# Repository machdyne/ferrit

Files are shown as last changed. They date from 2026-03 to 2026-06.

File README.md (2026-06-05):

# FERRIT Digital Archival Platform

FERRIT is a century-scale digital archival platform based on Ferroelectric RAM.

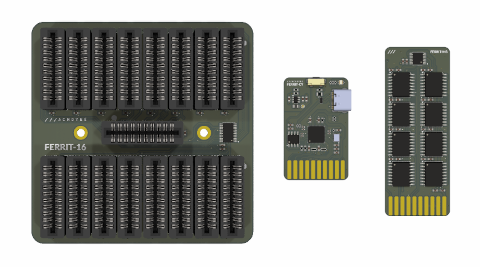
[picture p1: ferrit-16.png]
Ferrit


This repo contains PCB layouts, schematics, firmware and documentation.

Find more information on the [FERRIT project page](https://machdyne.com/ferrit/).

## Hardware

FERRIT is a modular upgradable system with 3 component types:

- A controller
- A backplane
- Removable ferroelectric memory cards

The controller communicates with the memory cards over a SPI/QSPI bus and exposes the memory to an interface, such as a USB mass storage device.

### Specifications

- Max capacity: 256MB+
- Max addressable memory devices per memory card: 16
- Max addressable memory devices per system: 256
- Interface: Depends on controller
- Speed: Depend on controller

*Note: The max capacity assumes double-sided memory cards with 1MB ICs. Higher capacities may be possible in the future.*

### Components

| Board | Type | Notes |
| ----- | ---- | ----- |
| FERRIT-CY | Controller | RP2040 / USB-FS |
| FERRIT-M8 | Memory card | 8 x SOP-16 |
| FERRIT-1 | Backplane + Controller | RP2040 / USB-FS / 1 memory card slot |
| FERRIT-8 | Backplane | 8 memory card slots (1U rack-mount) |
| FERRIT-16 | Backplane | 16 memory card slots |

## Firmware

The firmware can be updated by holding down the BOOT button while plugging in the USB cable, and then dragging and dropping a new UF2 file to the device.

You can build the firmware from source, if you have [pico-sdk](https://github.com/raspberrypi/pico-sdk) installed:

```
$ cd firmware/ferrit
$ mkdir build
$ cd build
$ cmake .. -DPICO_DEFAULT_BOOT_STAGE2_FILE=$PICO_SDK_PATH/src/rp2040/boot_stage2/boot2_generic_03h.S
$ make
```

## Pinouts

### Connector

The FERRIT controller and memory cards use the same form-factor and share certain signals:

| Pin | Controller | Memory Card |
| --- | --- | --- |
| 1 | QSPI\_SCLK | QSPI\_SCLK |
| 3 | GND | GND |
| 5 | QSPI\_SD0 | QSPI\_SD0 |
| 7 | GND | GND |
| 9 | QSPI\_SD1 | QSPI\_SD1 |
| 11 | GND | GND |
| 13 | QSPI\_SD2 | QSPI\_SD2 |
| 15 | GND | GND |
| 17 | QSPI\_SD3 | QSPI\_SD3 |
| 19 | GND | GND |
| 2 | QSPI\_SS | QSPI\_SS |
| 4 | SS0 | GND |
| 6 | CS0 | CS0 |
| 8 | CS1 | CS1 |
| 10 | CS2 | CS2 |
| 12 | CS3 | CS3 |
| 14 | SS1 | GND |
| 16 | SS2 | GND |
| 18 | SS3 | GND |
| 20 | PWR3V3 | PWR3V3 |

The slot select (SSx) signals determine which slot is selected, while the chip select (CSx) signals select an IC on that slot.

## License

The contents of this repo are released under the [Lone Dynamics Open License](LICENSE.md).

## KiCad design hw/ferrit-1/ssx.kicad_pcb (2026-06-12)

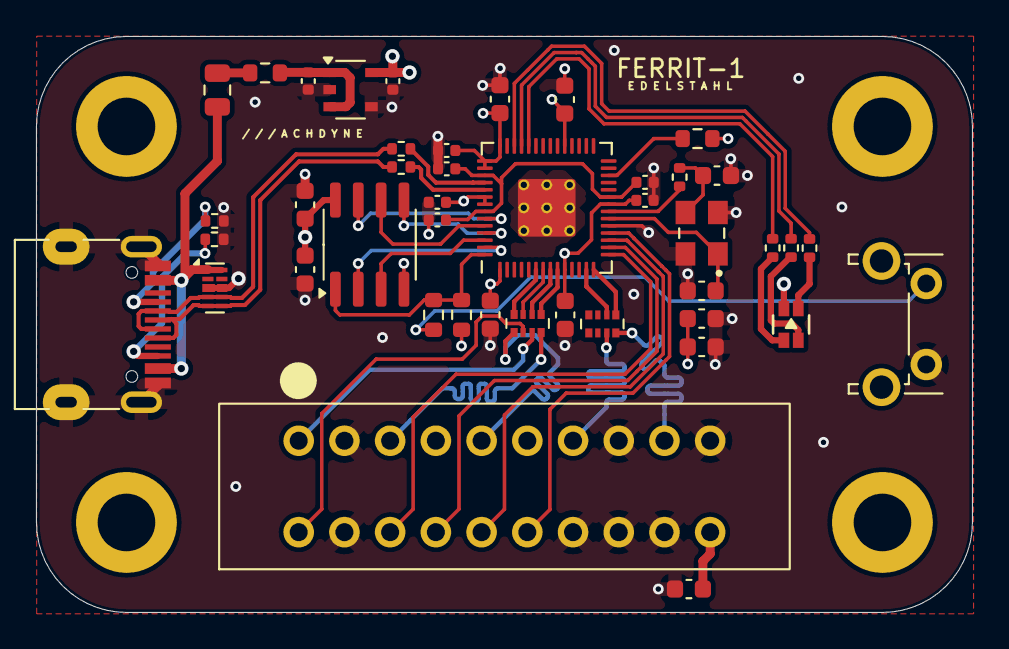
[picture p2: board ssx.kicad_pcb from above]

Board: 4 copper layers, 52.0 x 32.0 mm, 47 parts (0 on the bottom side), 45 nets.

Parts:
C1, C2: 15pF; C_0603_1608Metric
C3, C10, C16, C17: 1uF; C_0402_1005Metric
C4, C6, C8, C9: 100nF; C_0402_1005Metric
C5, C7, C11, C12, C13, C15: 100nF; C_0603_1608Metric
C14: 1uF; C_0603_1608Metric
C19, C20: 22uF; C_0603_1608Metric
D1: LED_RGB_ANODE; LED_RGB_0606_CHANZON
F1: Fuse_Small; Fuse_0805_2012Metric
FB1: Ferrite_Bead_Small; R_0603_1608Metric
H1, H2, H3, H4: MountingHole; MountingHole_3.2mm_M3_DIN965_Pad
J1: USB_C_Receptacle_USB2.0_16P; USB_C_Receptacle_HRO_TYPE-C-31-M-12-BIG-PADS-PASTE
J2: Conn_02x10_Odd_Even; MACHDYNE_EDGE_SOCKET_20P
R1, R7: 10K; R_0603_1608Metric
R2, R3: 27R; R_0402_1005Metric
R4, R11, R12, R13: 1K; R_0402_1005Metric
R5, R6: 5K1; R_0402_1005Metric
R8: 1K; R_0603_1608Metric
RN1, RN2: 33R; R_Array_Convex_4x0402
SW1: BOOT; SW_Tactile_SPST_Angled_PTS645Vx39-2LFS
U1: RP2040; RP2040-QFN-56-OFFICIAL
U2: TPD4E05U06DQAR; Diodes_UDFN-10_1.0x2.5mm_P0.5mm
U3: M95P32-IXMNT/E; SOIC-8_3.9x4.9mm_P1.27mm
U4: NCP115; TSOP-5_1.65x3.05mm_P0.95mm
Y1: ECS-80-12-33-JGN-TR-12MHZ; XTAL_ECS-240-8-33-AGN-TR

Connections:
/BOOT: R8.1, SW1.1
/CS0: J2.6, U1.15 (GPIO12)
/CS1: J2.8, U1.16 (GPIO13)
/CS2: J2.10, U1.17 (GPIO14)
/CS3: J2.12, U1.18 (GPIO15)
/KQSPI_SCLK: J2.1, RN1.7 (R2.2)
/KQSPI_SD0: J2.5, RN1.8 (R1.2)
/KQSPI_SD1: J2.9, RN1.5 (R4.2)
/KQSPI_SD2: J2.13, RN2.7 (R2.2)
/KQSPI_SD3: J2.17, RN2.8 (R1.2)
/KSS: J2.2, RN1.6 (R3.2)
/LEDB: R13.2, U1.40 (GPIO28/ADC2)
/LEDG: R12.2, U1.39 (GPIO27/ADC1)
/LEDR: R11.2, U1.38 (GPIO26/ADC0)
/PWR1V1: C6.1, C8.1, C10.1, U1.23 (DVDD), U1.45 (VREG_VOUT), U1.50 (DVDD)
/PWR3V3: C3.1, C4.1, C5.1, C7.1, C9.1, C11.1, C12.1, C13.1, C14.1, C15.1, C17.1, C19.1, C20.1, D1.1 (A), J2.20, R1.1, R7.1, U1.1 (IOVDD), U1.10 (IOVDD), U1.22 (IOVDD), U1.33 (IOVDD), U1.42 (IOVDD), U1.43 (ADC_AVDD), U1.44 (VREG_VIN), U1.48 (USB_VDD), U1.49 (IOVDD), U3.8 (VCC), U4.5 (OUT)
/PWR5V0: C16.1, FB1.1, U4.1 (IN), U4.3 (EN)
/QSPI_IO0: RN1.1 (R1.1), U1.9 (GPIO7)
/QSPI_IO1: RN1.4 (R4.1), U1.6 (GPIO4)
/QSPI_IO2: RN2.2 (R2.1), U1.13 (GPIO10)
/QSPI_IO3: RN2.1 (R1.1), U1.14 (GPIO11)
/QSPI_SCLK: RN1.2 (R2.1), U1.8 (GPIO6)
/RP_QSPI_IO0: U1.53 (QSPI_SD0), U3.5 (DI(IO0))
/RP_QSPI_IO1: U1.55 (QSPI_SD1), U3.2 (DO(IO1))
/RP_QSPI_IO2: U1.54 (QSPI_SD2), U3.3 (IO2)
/RP_QSPI_IO3: U1.51 (QSPI_SD3), U3.7 (IO3)
/RP_QSPI_SCK: U1.52 (QSPI_SCLK), U3.6 (CLK)
/RP_QSPI_SS: R7.2, R8.2, U1.56 (QSPI_CSN), U3.1 (~CS)
/RUN: R1.2, U1.26 (RUN)
/SS: RN1.3 (R3.1), U1.7 (GPIO5)
/USBCDN: J1.A7 (D-), J1.B7 (D-), R3.1, U2.4, U2.7
/USBCDP: J1.A6 (D+), J1.B6 (D+), R2.1, U2.5, U2.6
/USBC_CC1: J1.A5 (CC1), R5.2
/USBC_CC2: J1.B5 (CC2), R6.2
/USBDN: R3.2, U1.46 (USB_DM)
/USBDP: R2.2, U1.47 (USB_DP)
/VBUS: F1.1, J1.A4 (VBUS), J1.A9 (VBUS), J1.B4 (VBUS), J1.B9 (VBUS), U2.1, U2.10
/XIN: C1.2, U1.20 (XIN), Y1.1 (IN/OUT)
/XOUT: R4.2, U1.21 (XOUT)
GND: C1.1, C2.2, C3.2, C4.2, C5.2, C6.2, C7.2, C8.2, C9.2, C10.2, C11.2, C12.2, C13.2, C14.2, C15.2, C16.2, C17.2, C19.2, C20.2, J1.A1 (GND), J1.A12 (GND), J1.B1 (GND), J1.B12 (GND), J1.S1 (SHIELD), J2.3, J2.4, J2.7, J2.11, J2.14, J2.15, J2.16, J2.18, J2.19, R5.1, R6.1, SW1.2, U1.19 (TESTEN), U1.57 (GND), U2.3 (VSS), U2.8 (VSS), U3.4 (GND), U4.2 (GND), U4.4 (GND2), Y1.2 (GND), Y1.4 (GND)
unnamed: D1.2 (BK), R13.1
unnamed: D1.4 (GK), R12.1
unnamed: D1.3 (RK), R11.1
unnamed: F1.2, FB1.2
unnamed: C2.1, R4.1, Y1.3 (OUT/IN)

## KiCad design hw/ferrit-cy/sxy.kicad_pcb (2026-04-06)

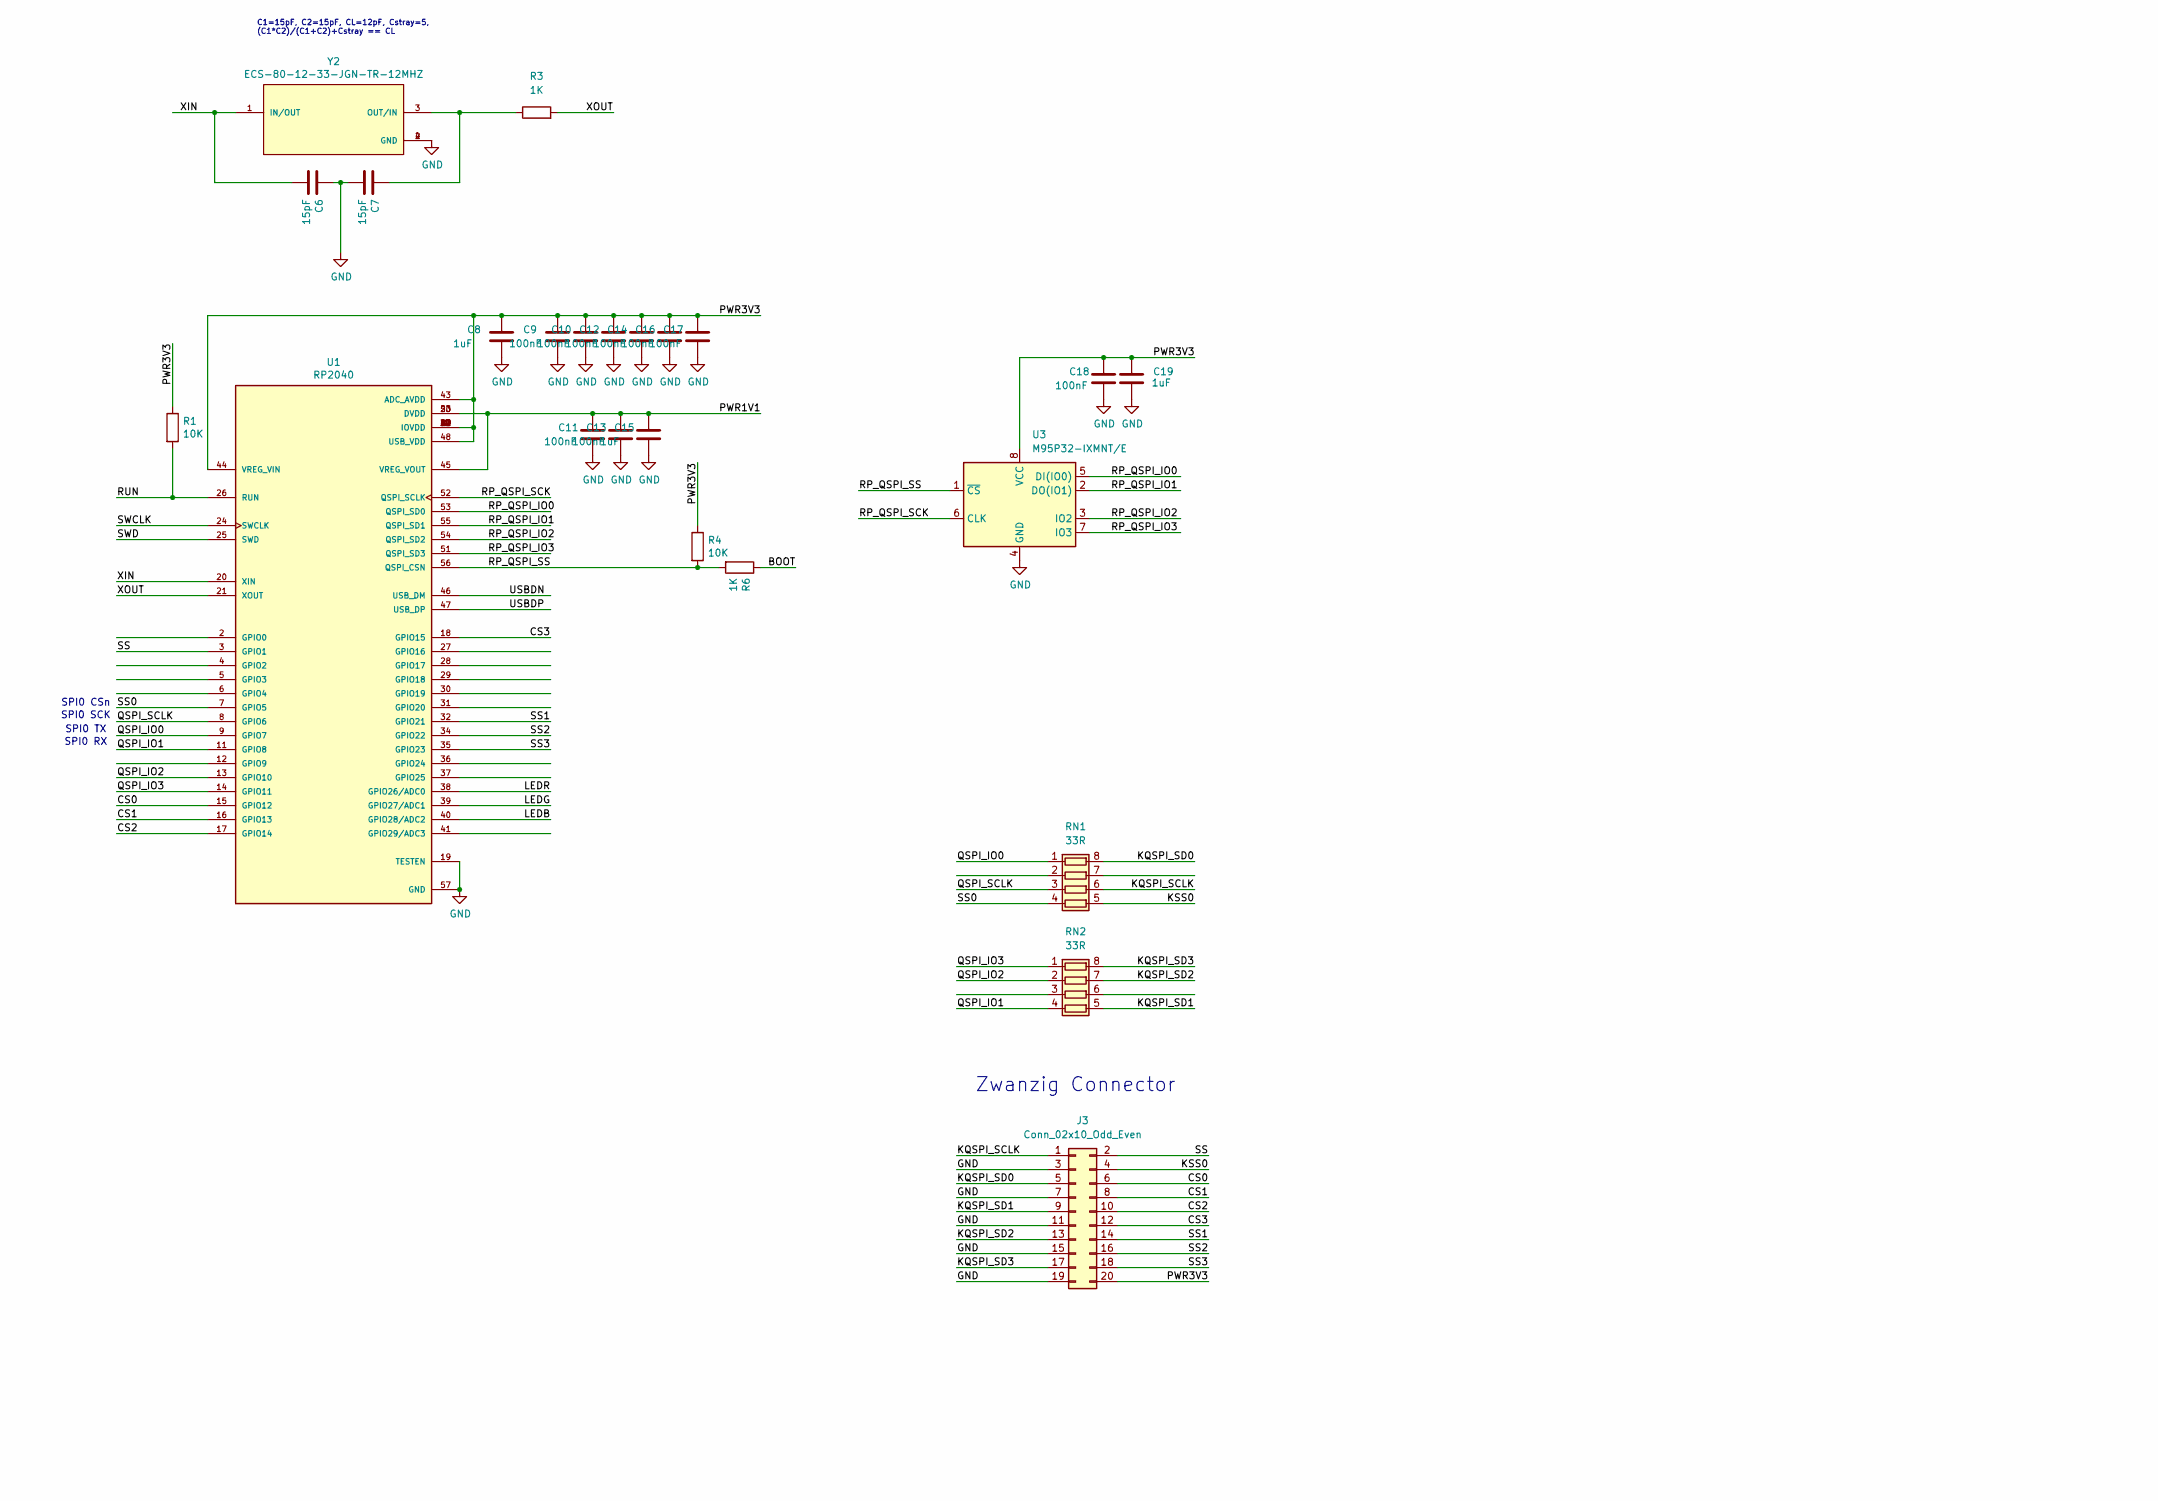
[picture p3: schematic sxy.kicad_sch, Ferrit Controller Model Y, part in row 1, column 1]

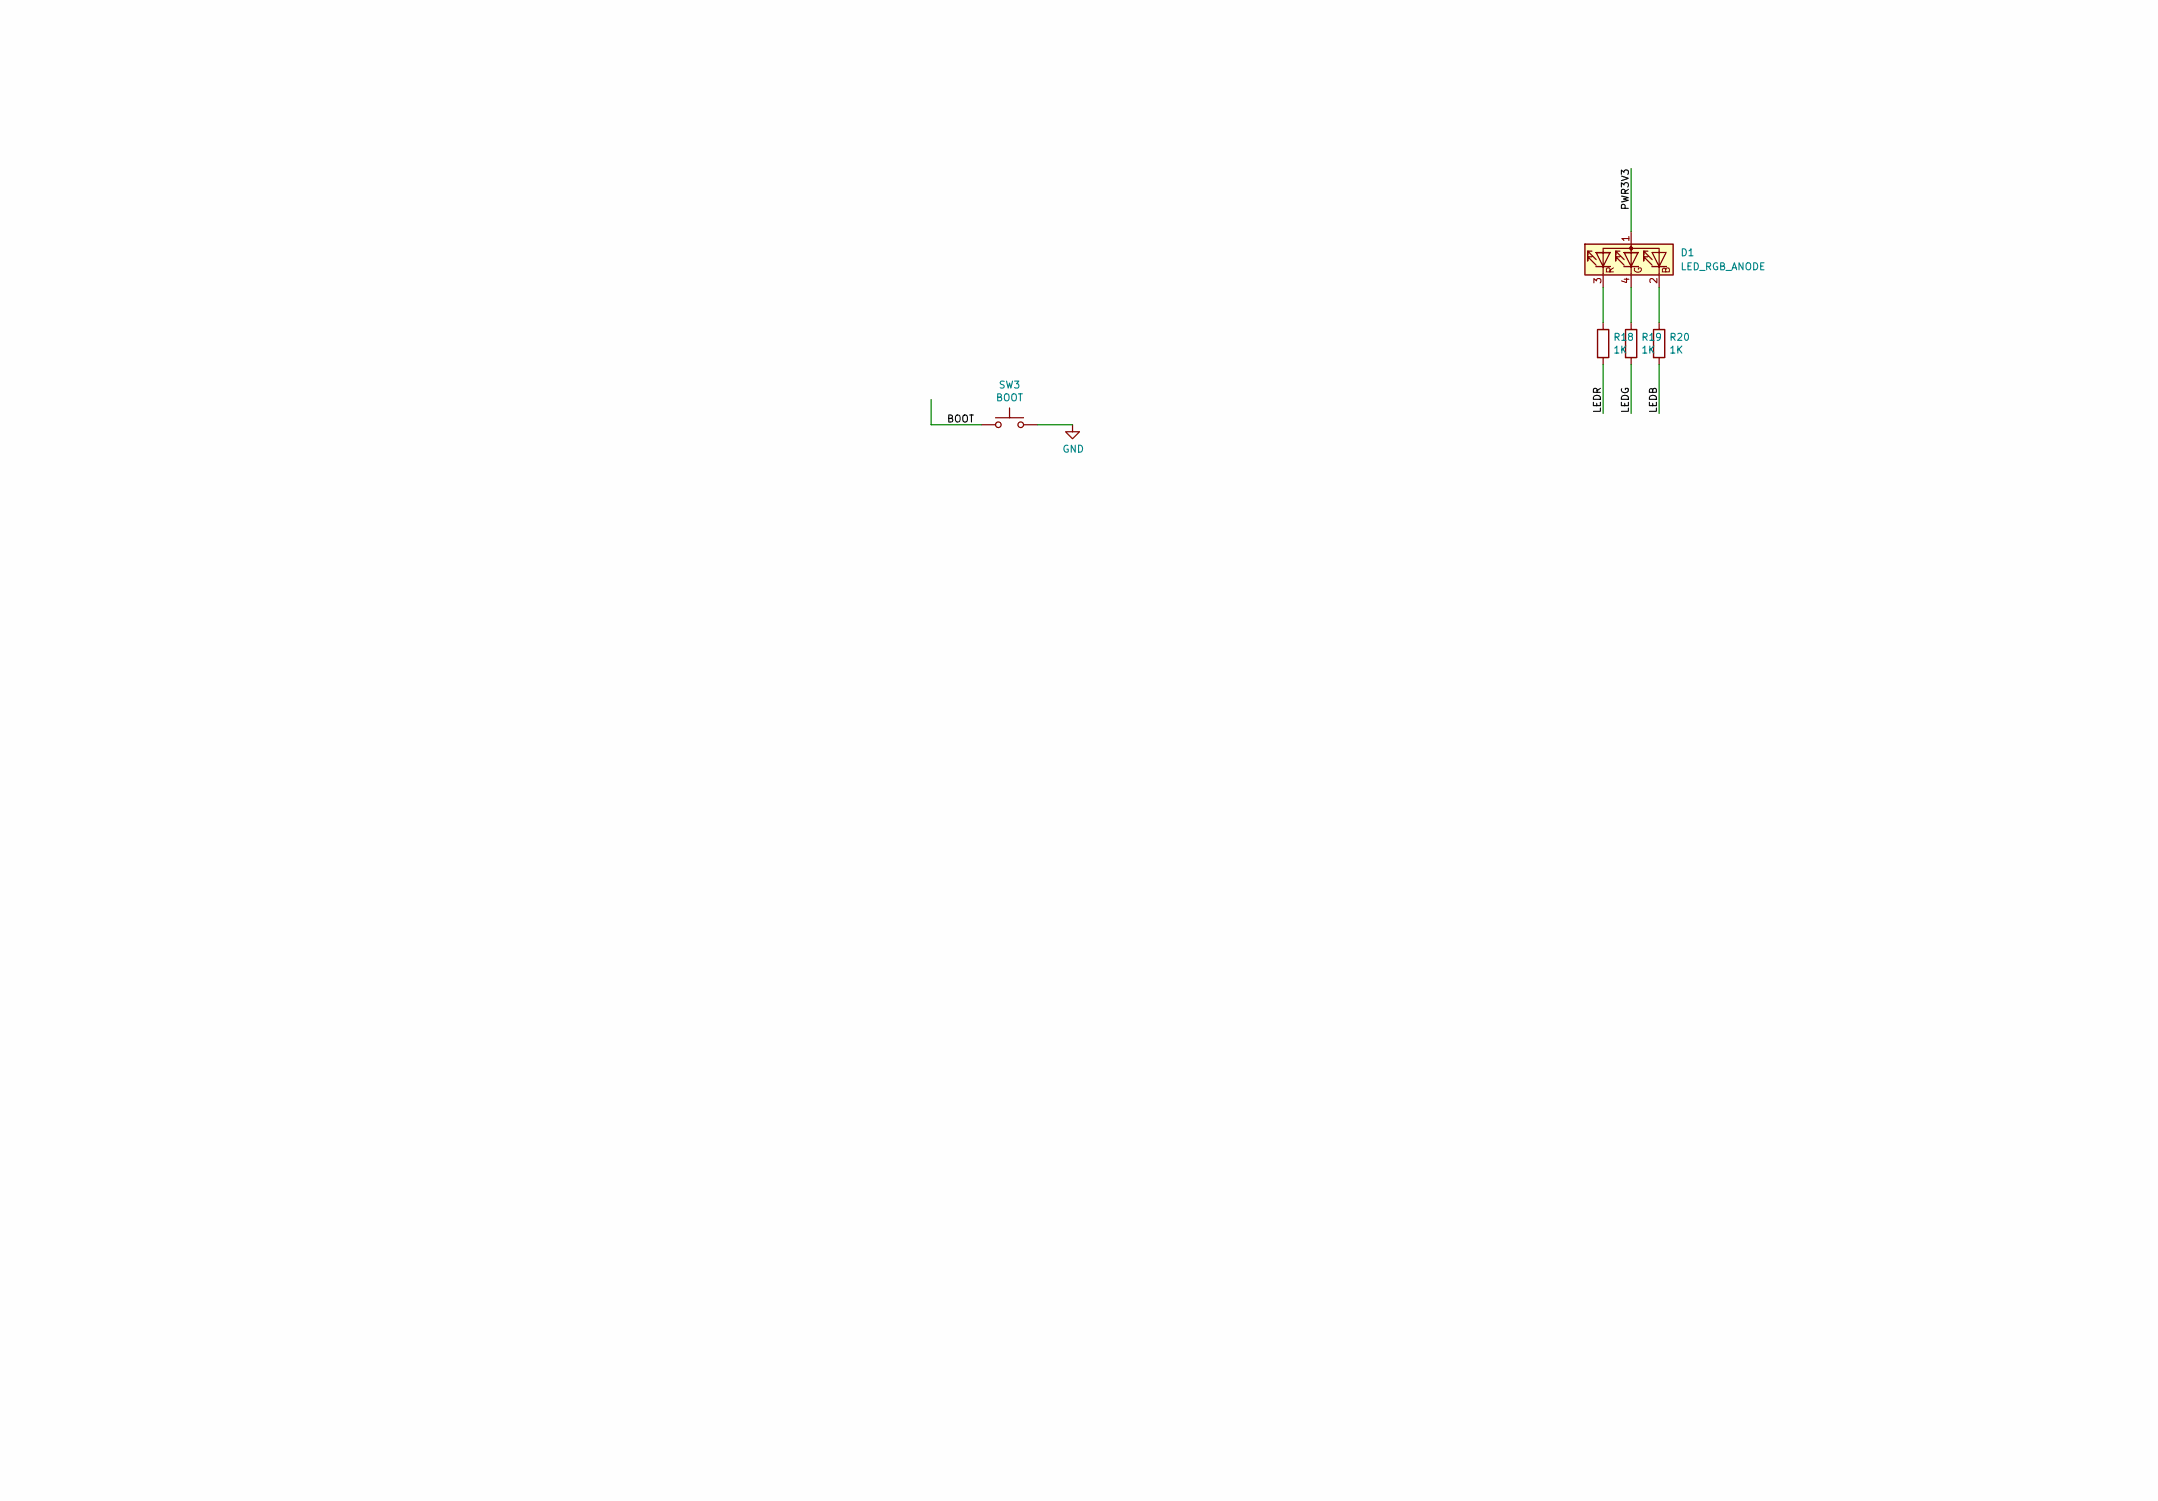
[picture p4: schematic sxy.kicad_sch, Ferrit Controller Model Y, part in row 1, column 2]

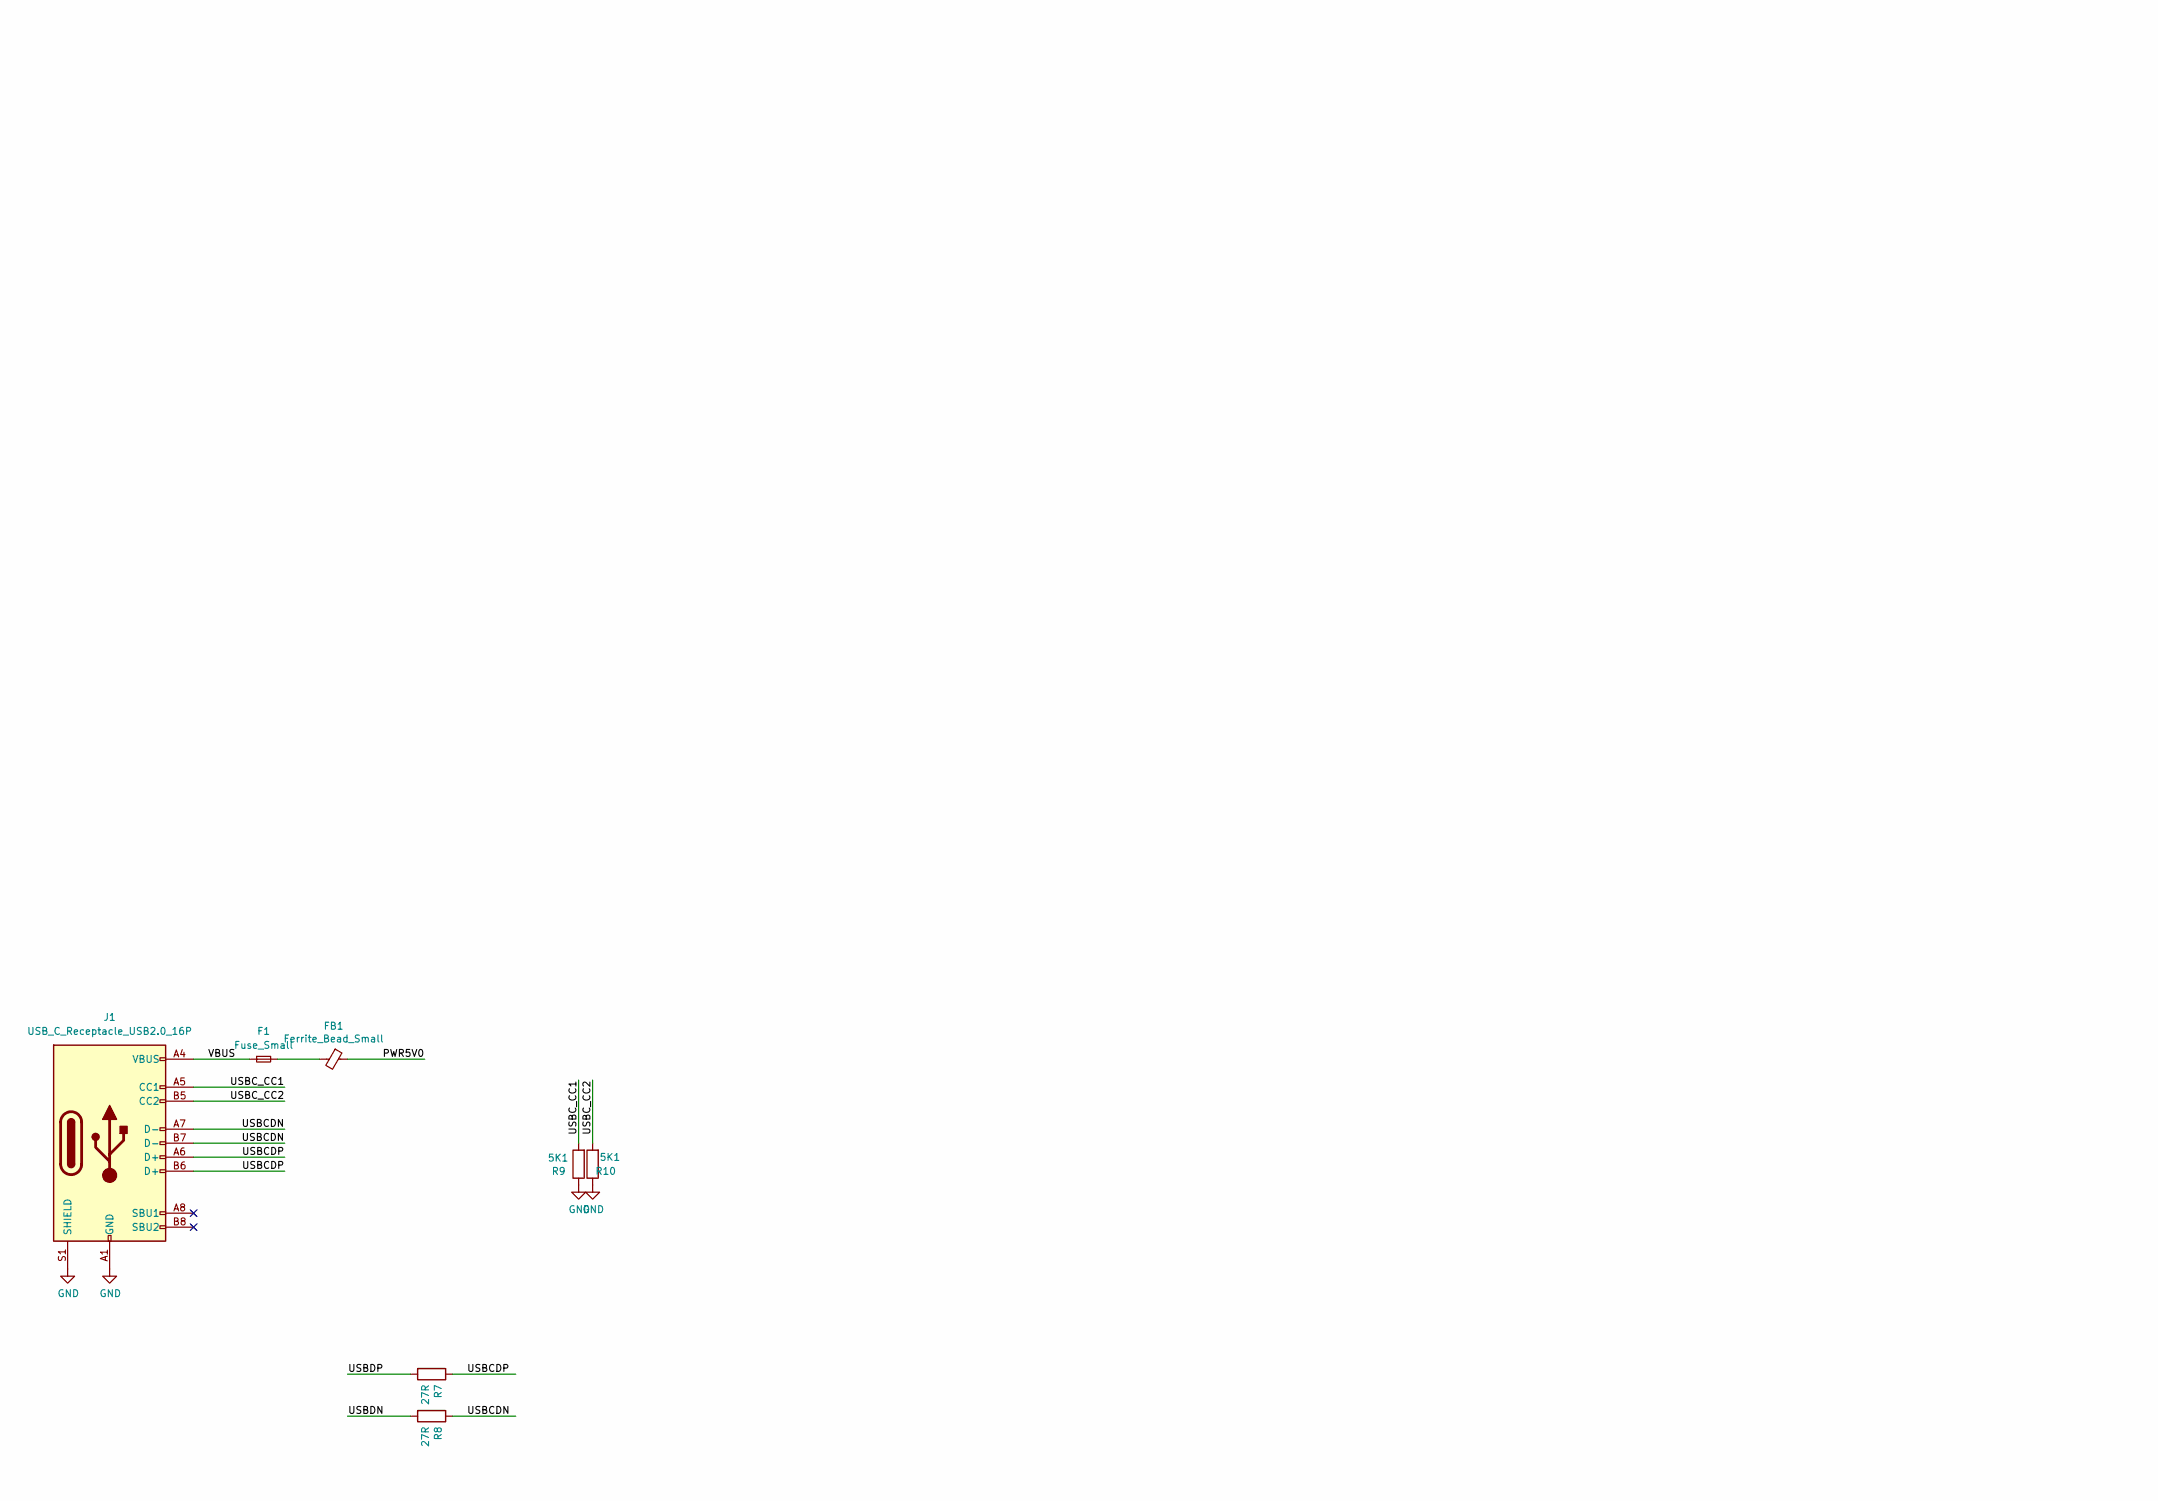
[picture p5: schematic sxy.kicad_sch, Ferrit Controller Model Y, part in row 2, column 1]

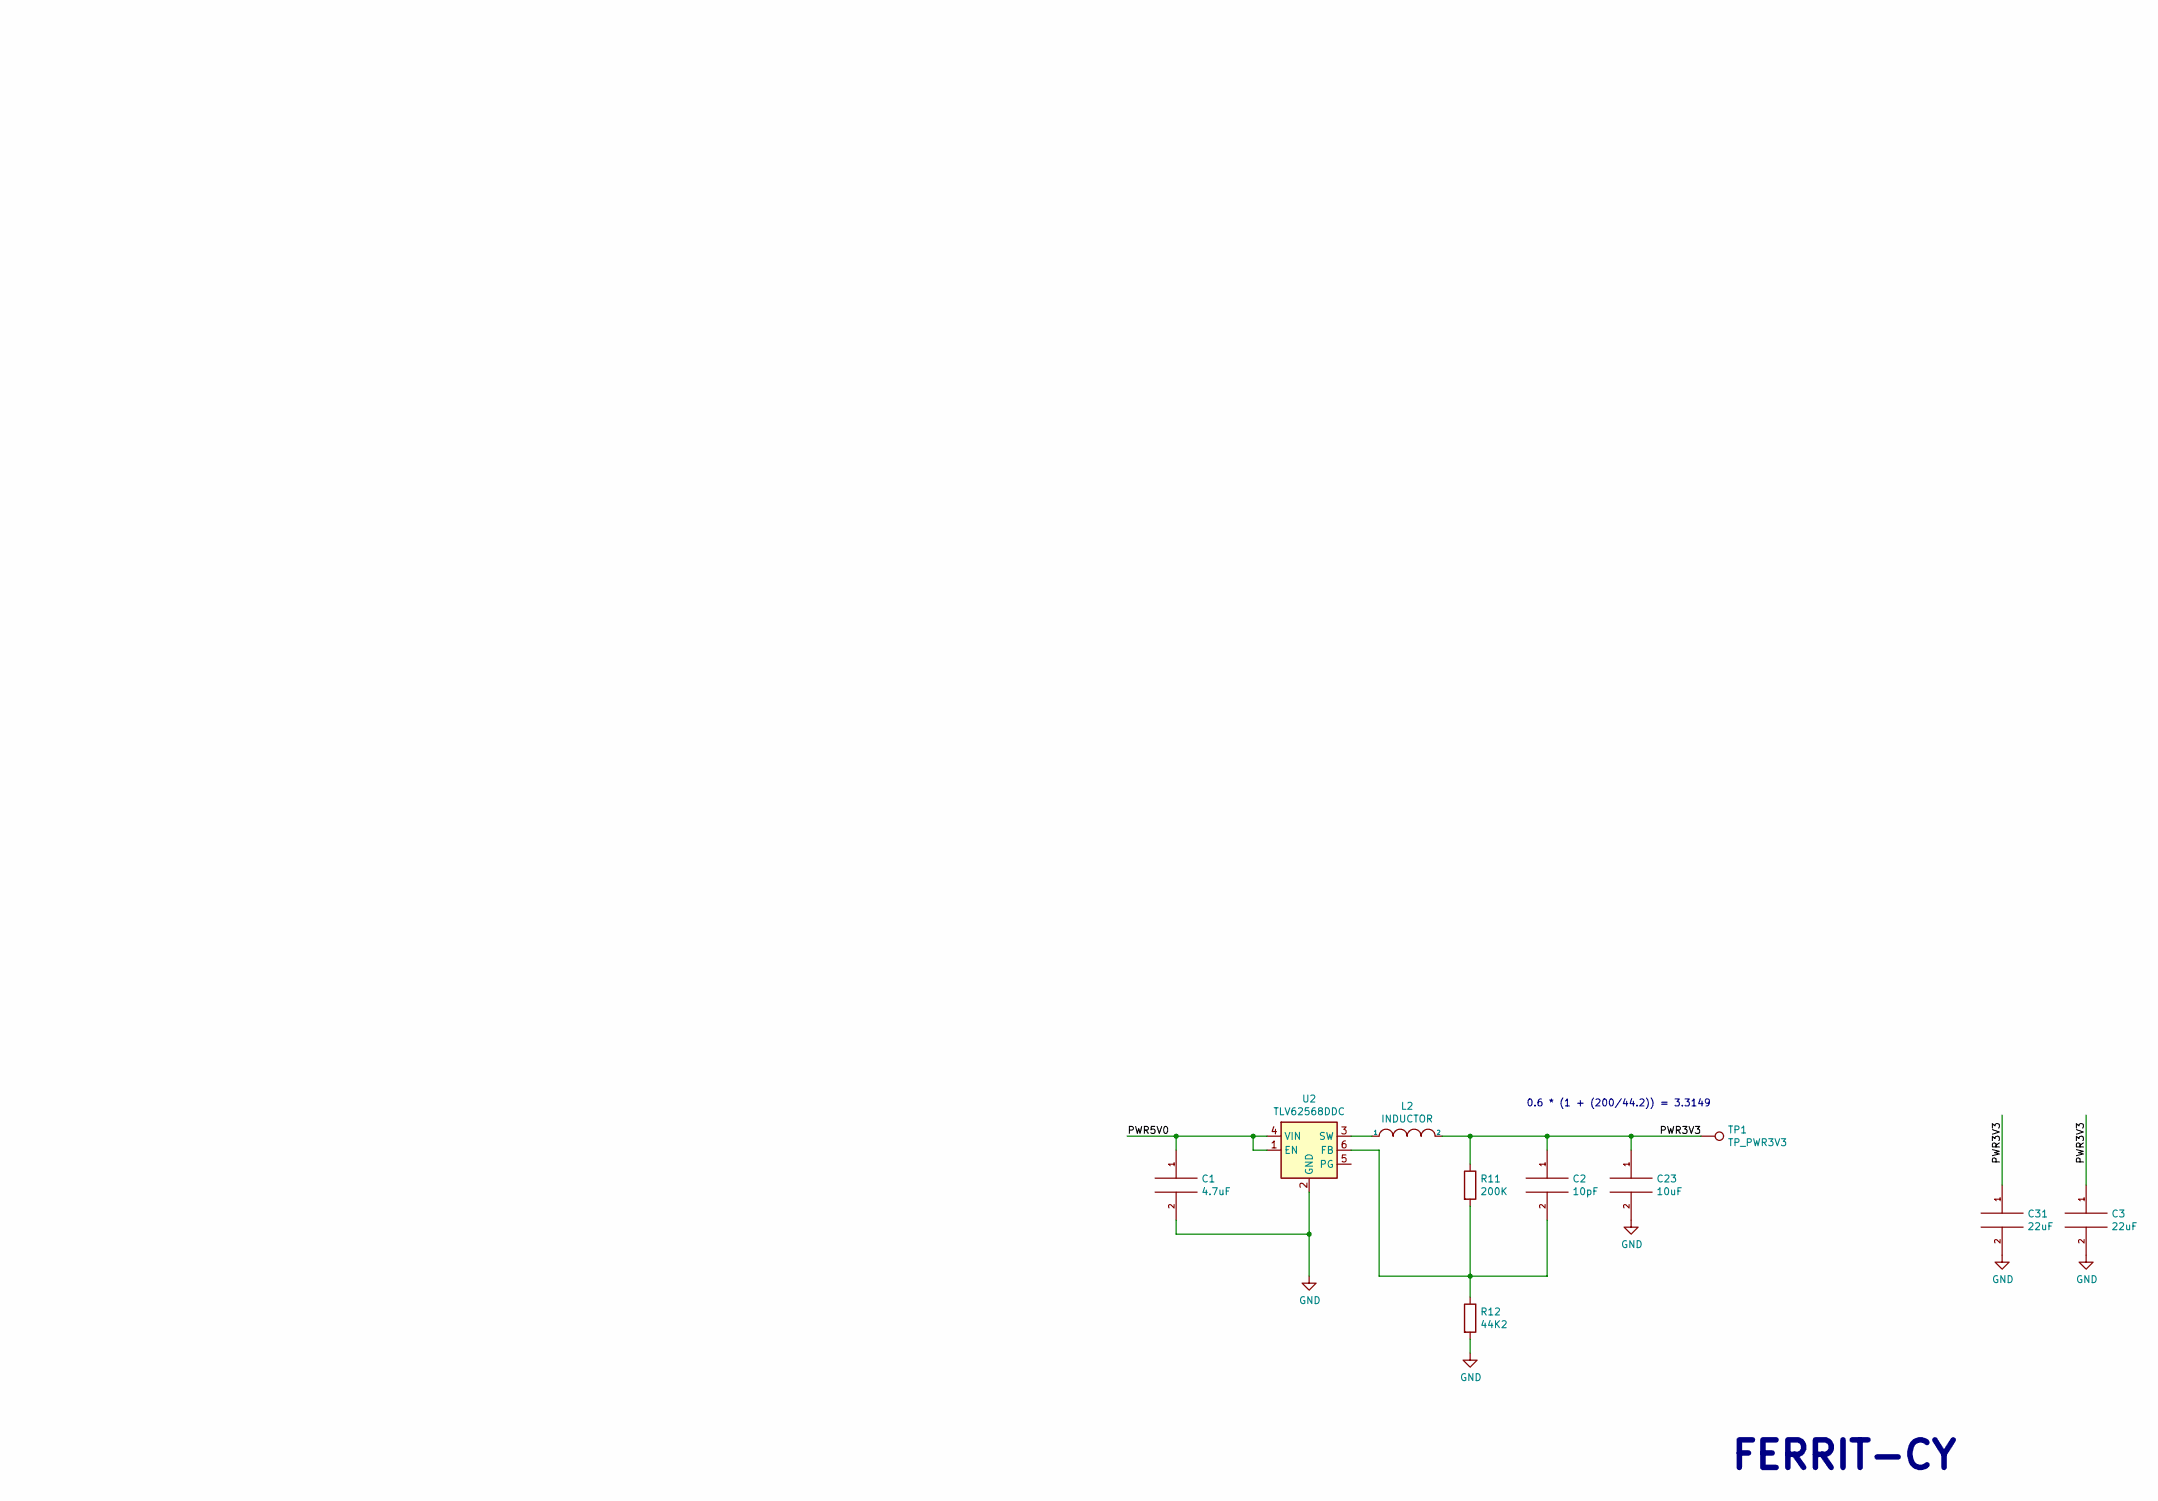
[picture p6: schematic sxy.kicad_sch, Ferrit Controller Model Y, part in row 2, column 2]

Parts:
C1: 4.7uF; C_0603_1608Metric
C2: 10pF; C_0603_1608Metric
C3, C31: 22uF; C_0603_1608Metric
C6, C7: 15pF; C_0603_1608Metric
C8, C15: 1uF; C_0402_1005Metric
C9, C11, C13, C14: 100nF; C_0402_1005Metric
C10, C12, C16, C17, C18: 100nF; C_0603_1608Metric
C19: 1uF; C_0603_1608Metric
C23: 10uF; C_0603_1608Metric
D1: LED_RGB_ANODE; LED_RGB_0606_CHANZON
F1: Fuse_Small; Fuse_0805_2012Metric
FB1: Ferrite_Bead_Small; R_0603_1608Metric
J1: USB_C_Receptacle_USB2.0_16P; USB_C_Receptacle_HRO_TYPE-C-31-M-12-BIG-PADS-PASTE
J3: Conn_02x10_Odd_Even; MACHDYNE_EDGE_20P
L2: INDUCTOR; L_0805_2012Metric
R1, R4: 10K; R_0603_1608Metric
R3, R18, R19, R20: 1K; R_0402_1005Metric
R6: 1K; R_0603_1608Metric
R7, R8: 27R; R_0402_1005Metric
R9, R10: 5K1; R_0402_1005Metric
R11: 200K; R_0603_1608Metric
R12: 44K2; R_0603_1608Metric
RN1, RN2: 33R; R_Array_Convex_4x0402
SW3: BOOT; SW_SMD_2P_3X6MM
TP1: TP_PWR3V3; TestPoint_THTPad_D1.0mm_Drill0.5mm
U1: RP2040; RP2040-QFN-56-OFFICIAL; PARTREV 1.6.1
U2: TLV62568DDC; SOT-23-6
U3: M95P32-IXMNT/E; SOIC-8_3.9x4.9mm_P1.27mm
Y2: ECS-80-12-33-JGN-TR-12MHZ; XTAL_ECS-240-8-33-AGN-TR

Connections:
/BOOT: R6.1, SW3.1
/CS0: J3.6, U1.15 (GPIO12)
/CS1: J3.8, U1.16 (GPIO13)
/CS2: J3.10, U1.17 (GPIO14)
/CS3: J3.12, U1.18 (GPIO15)
/KQSPI_SCLK: J3.1, RN1.6 (R3.2)
/KQSPI_SD0: J3.5, RN1.8 (R1.2)
/KQSPI_SD1: J3.9, RN2.5 (R4.2)
/KQSPI_SD2: J3.13, RN2.7 (R2.2)
/KQSPI_SD3: J3.17, RN2.8 (R1.2)
/KSS0: J3.4, RN1.5 (R4.2)
/LEDB: R20.2, U1.40 (GPIO28/ADC2)
/LEDG: R19.2, U1.39 (GPIO27/ADC1)
/LEDR: R18.2, U1.38 (GPIO26/ADC0)
/PWR1V1: C11.1, C13.1, C15.1, U1.23 (DVDD), U1.45 (VREG_VOUT), U1.50 (DVDD)
/PWR3V3: C2.1, C3.1, C8.1, C9.1, C10.1, C12.1, C14.1, C16.1, C17.1, C18.1, C19.1, C23.1, C31.1, D1.1 (A), J3.20, L2.2, R1.1, R4.1, R11.1, TP1.1, U1.1 (IOVDD), U1.10 (IOVDD), U1.22 (IOVDD), U1.33 (IOVDD), U1.42 (IOVDD), U1.43 (ADC_AVDD), U1.44 (VREG_VIN), U1.48 (USB_VDD), U1.49 (IOVDD), U3.8 (VCC)
/PWR5V0: C1.1, FB1.1, U2.1 (EN), U2.4 (VIN)
/QSPI_IO0: RN1.1 (R1.1), U1.9 (GPIO7)
/QSPI_IO1: RN2.4 (R4.1), U1.11 (GPIO8)
/QSPI_IO2: RN2.2 (R2.1), U1.13 (GPIO10)
/QSPI_IO3: RN2.1 (R1.1), U1.14 (GPIO11)
/QSPI_SCLK: RN1.3 (R3.1), U1.8 (GPIO6)
/RP_QSPI_IO0: U1.53 (QSPI_SD0), U3.5 (DI(IO0))
/RP_QSPI_IO1: U1.55 (QSPI_SD1), U3.2 (DO(IO1))
/RP_QSPI_IO2: U1.54 (QSPI_SD2), U3.3 (IO2)
/RP_QSPI_IO3: U1.51 (QSPI_SD3), U3.7 (IO3)
/RP_QSPI_SCK: U1.52 (QSPI_SCLK), U3.6 (CLK)
/RP_QSPI_SS: R4.2, R6.2, U1.56 (QSPI_CSN), U3.1 (~CS)
/RUN: R1.2, U1.26 (RUN)
/SS: J3.2, U1.3 (GPIO1)
/SS0: RN1.4 (R4.1), U1.7 (GPIO5)
/SS1: J3.14, U1.32 (GPIO21)
/SS2: J3.16, U1.34 (GPIO22)
/SS3: J3.18, U1.35 (GPIO23)
/SWCLK: U1.24 (SWCLK)
/SWD: U1.25 (SWD)
/USBCDN: J1.A7 (D-), J1.B7 (D-), R8.1
/USBCDP: J1.A6 (D+), J1.B6 (D+), R7.1
/USBC_CC1: J1.A5 (CC1), R9.2
/USBC_CC2: J1.B5 (CC2), R10.2
/USBDN: R8.2, U1.46 (USB_DM)
/USBDP: R7.2, U1.47 (USB_DP)
/VBUS: F1.1, J1.A4 (VBUS), J1.A9 (VBUS), J1.B4 (VBUS), J1.B9 (VBUS)
/XIN: C6.2, U1.20 (XIN), Y2.1 (IN/OUT)
/XOUT: R3.2, U1.21 (XOUT)
GND: C1.2, C3.2, C6.1, C7.2, C8.2, C9.2, C10.2, C11.2, C12.2, C13.2, C14.2, C15.2, C16.2, C17.2, C18.2, C19.2, C23.2, C31.2, J1.A1 (GND), J1.A12 (GND), J1.B1 (GND), J1.B12 (GND), J1.S1 (SHIELD), J3.3, J3.7, J3.11, J3.15, J3.19, R9.1, R10.1, R12.2, SW3.2, U1.19 (TESTEN), U1.57 (GND), U2.2 (GND), U3.4 (GND), Y2.2 (GND), Y2.4 (GND)
unnamed: D1.2 (BK), R20.1
unnamed: D1.4 (GK), R19.1
unnamed: D1.3 (RK), R18.1
unnamed: F1.2, FB1.2
unnamed: C2.2, R11.2, R12.1, U2.6 (FB)
unnamed: L2.1, U2.3 (SW)
unnamed: C7.1, R3.1, Y2.3 (OUT/IN)

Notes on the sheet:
FERRIT-CY
0.6 * (1 + (200/44.2)) = 3.3149
SPI0 TX
C1=15pF, C2=15pF, CL=12pF, Cstray=5, (C1*C2)/(C1+C2)+Cstray == CL
Zwanzig Connector
SPI0 SCK
SPI0 CSn
SPI0 RX

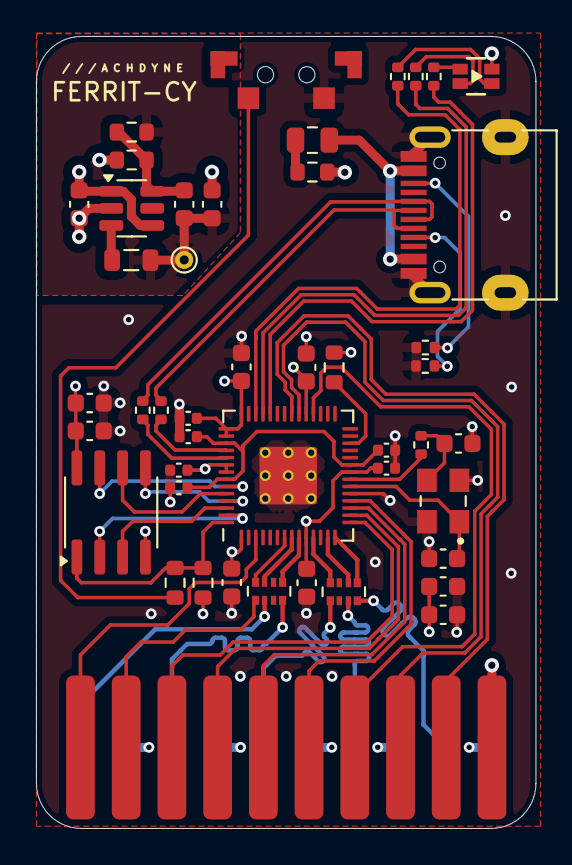
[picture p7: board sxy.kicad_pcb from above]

Board: 4 copper layers, 27.8 x 44.0 mm, 46 parts (0 on the bottom side), 51 nets.

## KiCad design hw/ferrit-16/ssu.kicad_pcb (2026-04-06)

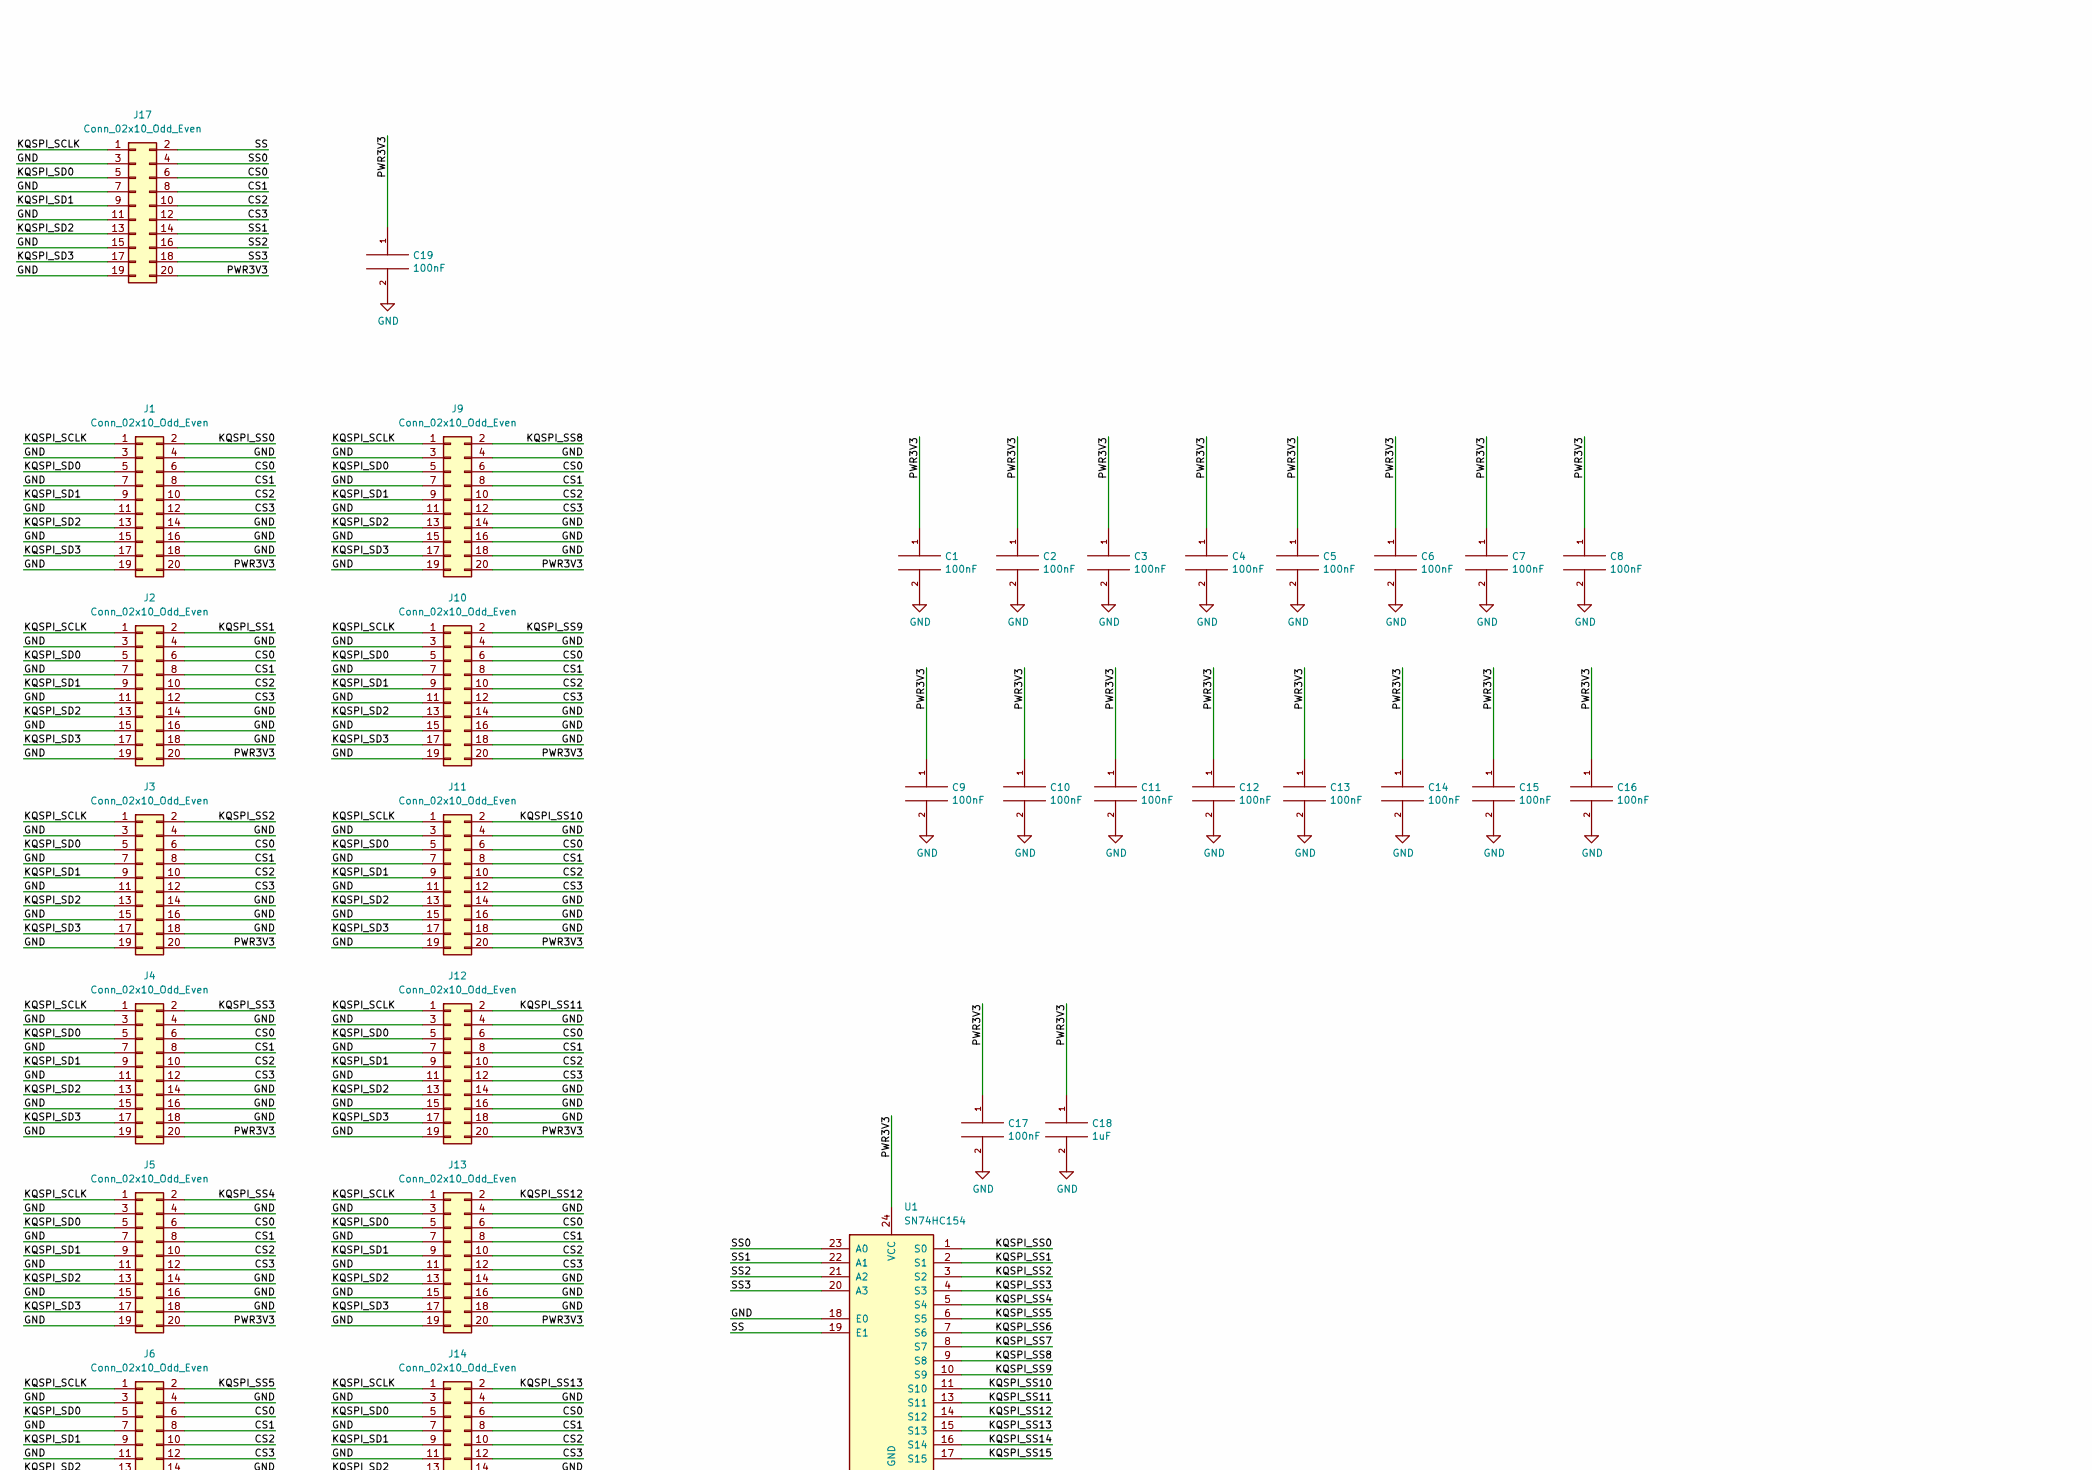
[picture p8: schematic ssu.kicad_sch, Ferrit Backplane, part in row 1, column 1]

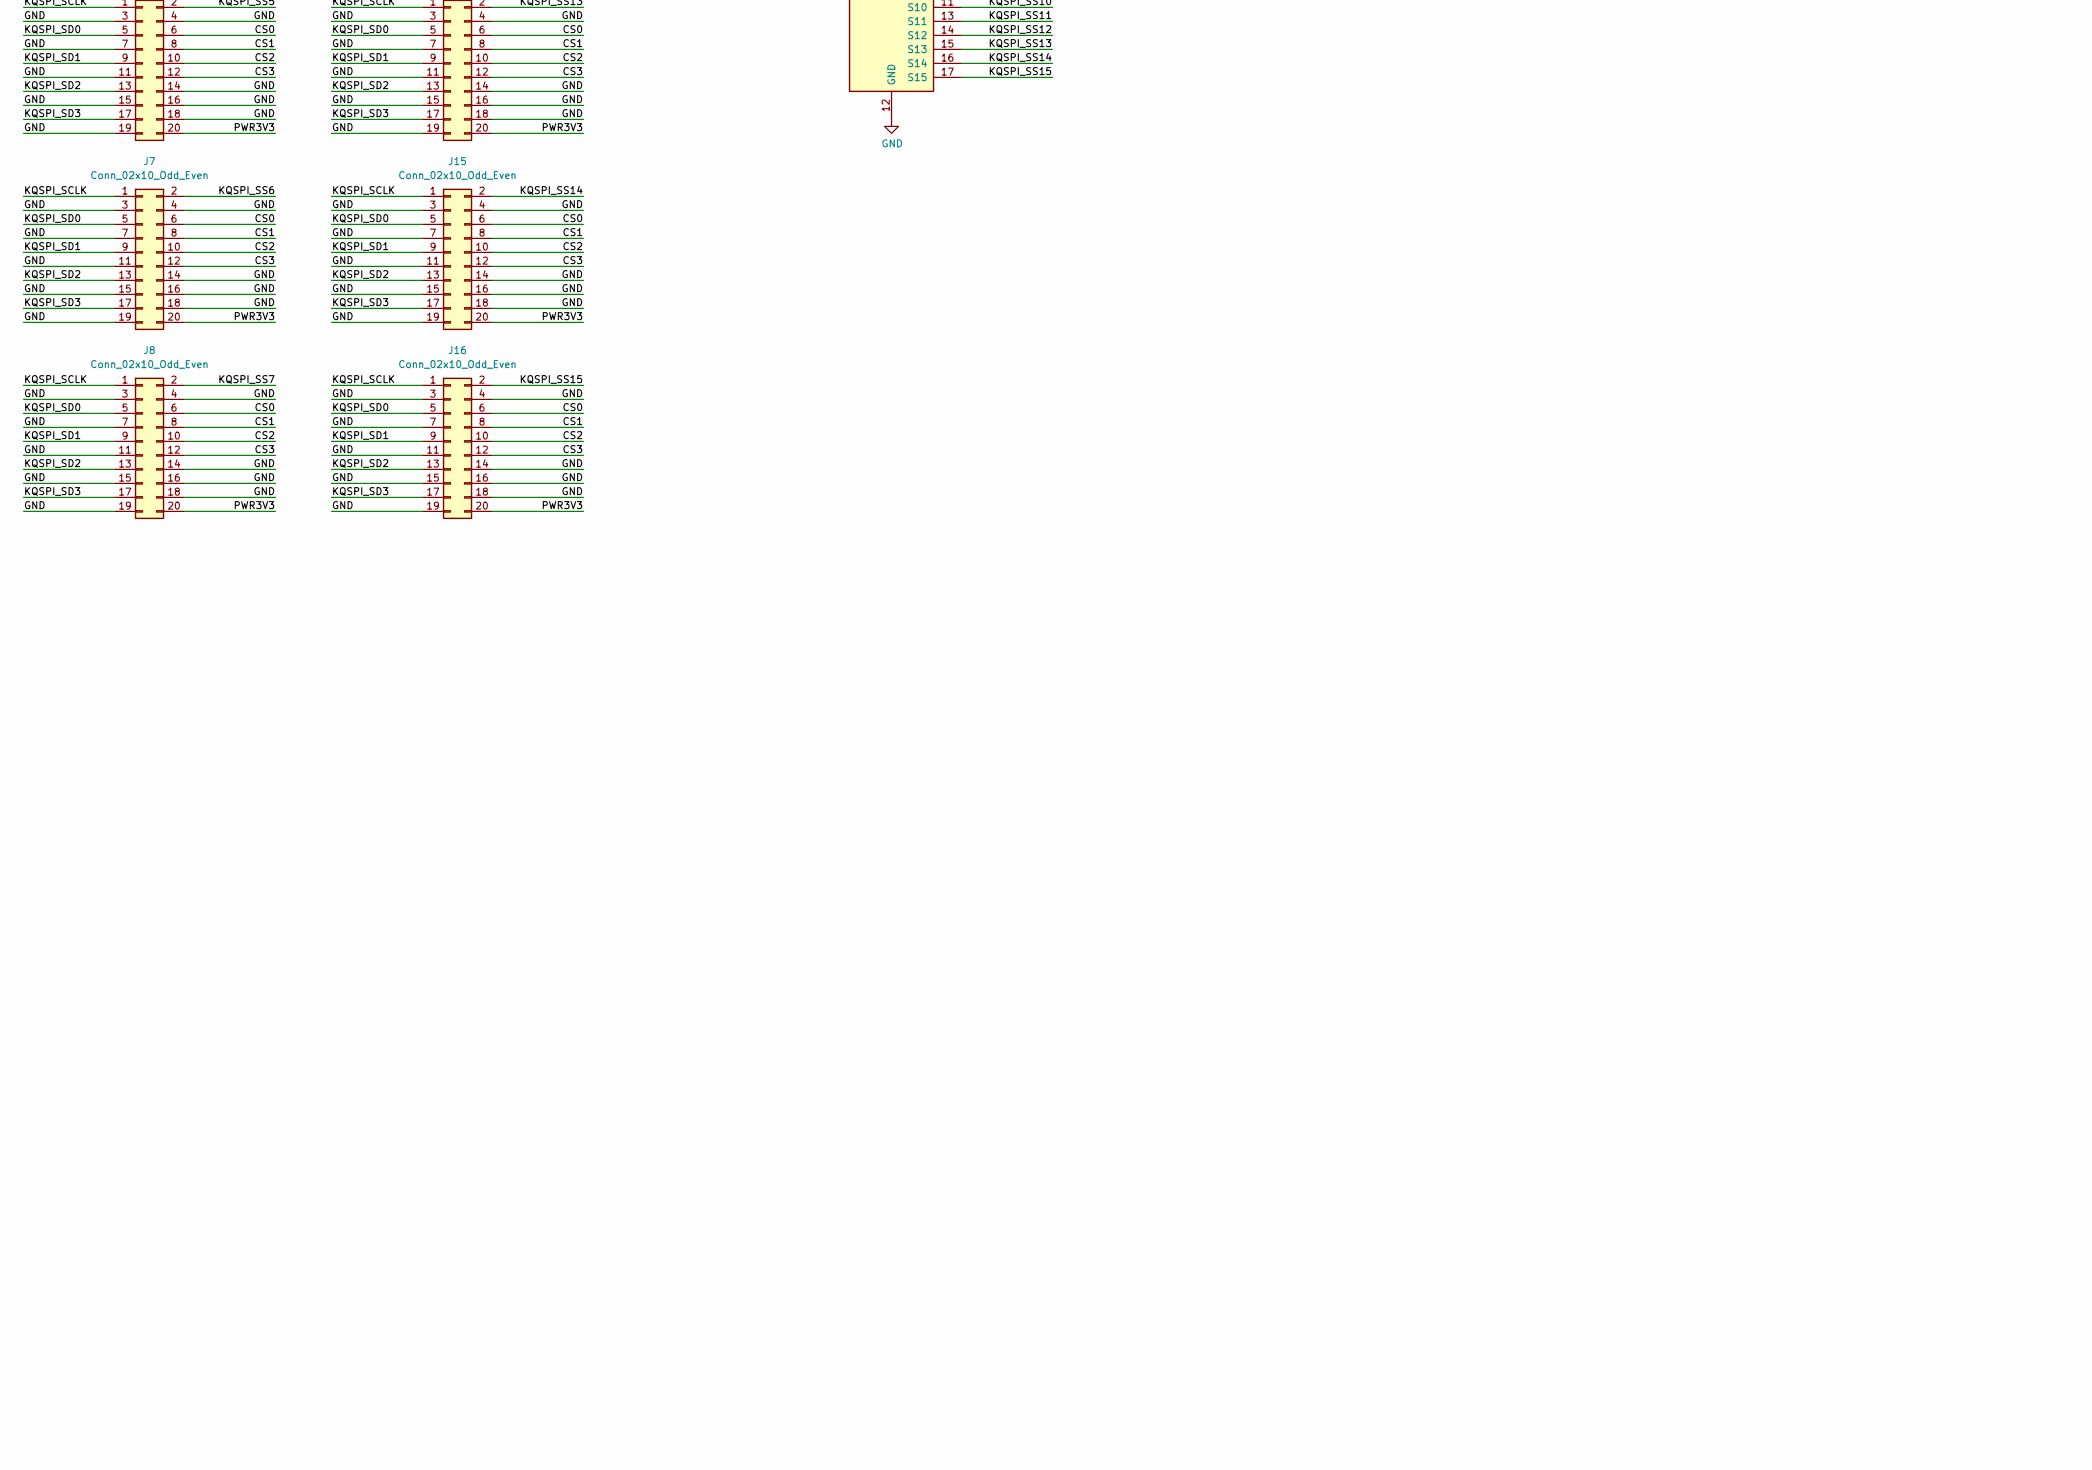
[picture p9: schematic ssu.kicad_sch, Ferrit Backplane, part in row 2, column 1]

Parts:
C1, C2, C3, C4, C5, C6, C7, C8, C9, C10, C11, C12, C13, C14, C15, C16, C17, C19: 100nF; C_0603_1608Metric
C18: 1uF; C_0603_1608Metric
H1, H2: MountingHole; MountingHole_3.2mm_M3_DIN965_Pad
J1, J2, J3, J4, J5, J6, J7, J8, J9, J10, J11, J12, J13, J14, J15, J16, J17: Conn_02x10_Odd_Even; MACHDYNE_EDGE_SOCKET_20P
U1: SN74HC154; TSSOP-24_4.4x7.8mm_P0.65mm

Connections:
/CS0: J1.6, J2.6, J3.6, J4.6, J5.6, J6.6, J7.6, J8.6, J9.6, J10.6, J11.6, J12.6, J13.6, J14.6, J15.6, J16.6, J17.6
/CS1: J1.8, J2.8, J3.8, J4.8, J5.8, J6.8, J7.8, J8.8, J9.8, J10.8, J11.8, J12.8, J13.8, J14.8, J15.8, J16.8, J17.8
/CS2: J1.10, J2.10, J3.10, J4.10, J5.10, J6.10, J7.10, J8.10, J9.10, J10.10, J11.10, J12.10, J13.10, J14.10, J15.10, J16.10, J17.10
/CS3: J1.12, J2.12, J3.12, J4.12, J5.12, J6.12, J7.12, J8.12, J9.12, J10.12, J11.12, J12.12, J13.12, J14.12, J15.12, J16.12, J17.12
/KQSPI_SCLK: J1.1, J2.1, J3.1, J4.1, J5.1, J6.1, J7.1, J8.1, J9.1, J10.1, J11.1, J12.1, J13.1, J14.1, J15.1, J16.1, J17.1
/KQSPI_SD0: J1.5, J2.5, J3.5, J4.5, J5.5, J6.5, J7.5, J8.5, J9.5, J10.5, J11.5, J12.5, J13.5, J14.5, J15.5, J16.5, J17.5
/KQSPI_SD1: J1.9, J2.9, J3.9, J4.9, J5.9, J6.9, J7.9, J8.9, J9.9, J10.9, J11.9, J12.9, J13.9, J14.9, J15.9, J16.9, J17.9
/KQSPI_SD2: J1.13, J2.13, J3.13, J4.13, J5.13, J6.13, J7.13, J8.13, J9.13, J10.13, J11.13, J12.13, J13.13, J14.13, J15.13, J16.13, J17.13
/KQSPI_SD3: J1.17, J2.17, J3.17, J4.17, J5.17, J6.17, J7.17, J8.17, J9.17, J10.17, J11.17, J12.17, J13.17, J14.17, J15.17, J16.17, J17.17
/KQSPI_SS0: J1.2, U1.1 (S0)
/KQSPI_SS1: J2.2, U1.2 (S1)
/KQSPI_SS2: J3.2, U1.3 (S2)
/KQSPI_SS3: J4.2, U1.4 (S3)
/KQSPI_SS4: J5.2, U1.5 (S4)
/KQSPI_SS5: J6.2, U1.6 (S5)
/KQSPI_SS6: J7.2, U1.7 (S6)
/KQSPI_SS7: J8.2, U1.8 (S7)
/KQSPI_SS8: J9.2, U1.9 (S8)
/KQSPI_SS9: J10.2, U1.10 (S9)
/KQSPI_SS10: J11.2, U1.11 (S10)
/KQSPI_SS11: J12.2, U1.13 (S11)
/KQSPI_SS12: J13.2, U1.14 (S12)
/KQSPI_SS13: J14.2, U1.15 (S13)
/KQSPI_SS14: J15.2, U1.16 (S14)
/KQSPI_SS15: J16.2, U1.17 (S15)
/PWR3V3: C1.1, C2.1, C3.1, C4.1, C5.1, C6.1, C7.1, C8.1, C9.1, C10.1, C11.1, C12.1, C13.1, C14.1, C15.1, C16.1, C17.1, C18.1, C19.1, J1.20, J2.20, J3.20, J4.20, J5.20, J6.20, J7.20, J8.20, J9.20, J10.20, J11.20, J12.20, J13.20, J14.20, J15.20, J16.20, J17.20, U1.24 (VCC)
/SS: J17.2, U1.19 (E1)
/SS0: J17.4, U1.23 (A0)
/SS1: J17.14, U1.22 (A1)
/SS2: J17.16, U1.21 (A2)
/SS3: J17.18, U1.20 (A3)
GND: C1.2, C2.2, C3.2, C4.2, C5.2, C6.2, C7.2, C8.2, C9.2, C10.2, C11.2, C12.2, C13.2, C14.2, C15.2, C16.2, C17.2, C18.2, C19.2, J1.3, J1.4, J1.7, J1.11, J1.14, J1.15, J1.16, J1.18, J1.19, J2.3, J2.4, J2.7, J2.11, J2.14, J2.15, J2.16, J2.18, J2.19, J3.3, J3.4, J3.7, J3.11, J3.14, J3.15, J3.16, J3.18, J3.19, J4.3, J4.4, J4.7, J4.11, J4.14, J4.15, J4.16, J4.18, J4.19, J5.3, J5.4, J5.7, J5.11, J5.14, J5.15, J5.16, J5.18, J5.19, J6.3, J6.4, J6.7, J6.11, J6.14, J6.15, J6.16, J6.18, J6.19, J7.3, J7.4, J7.7, J7.11, J7.14, J7.15, J7.16, J7.18, J7.19, J8.3, J8.4, J8.7, J8.11, J8.14, J8.15, J8.16, J8.18, J8.19, J9.3, J9.4, J9.7, J9.11, J9.14, J9.15, J9.16, J9.18, J9.19, J10.3, J10.4, J10.7, J10.11, J10.14, J10.15, J10.16, J10.18, J10.19, J11.3, J11.4, J11.7, J11.11, J11.14, J11.15, J11.16, J11.18, J11.19, J12.3, J12.4, J12.7, J12.11, J12.14, J12.15, J12.16, J12.18, J12.19, J13.3, J13.4, J13.7, J13.11, J13.14, J13.15, J13.16, J13.18, J13.19, J14.3, J14.4, J14.7, J14.11, J14.14, J14.15, J14.16, J14.18, J14.19, J15.3, J15.4, J15.7, J15.11, J15.14, J15.15, J15.16, J15.18, J15.19, J16.3, J16.4, J16.7, J16.11, J16.14, J16.15, J16.16, J16.18, J16.19, J17.3, J17.7, J17.11, J17.15, J17.19, U1.12 (GND), U1.18 (E0)

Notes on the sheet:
U B E R S T A H L
FERRIT-16

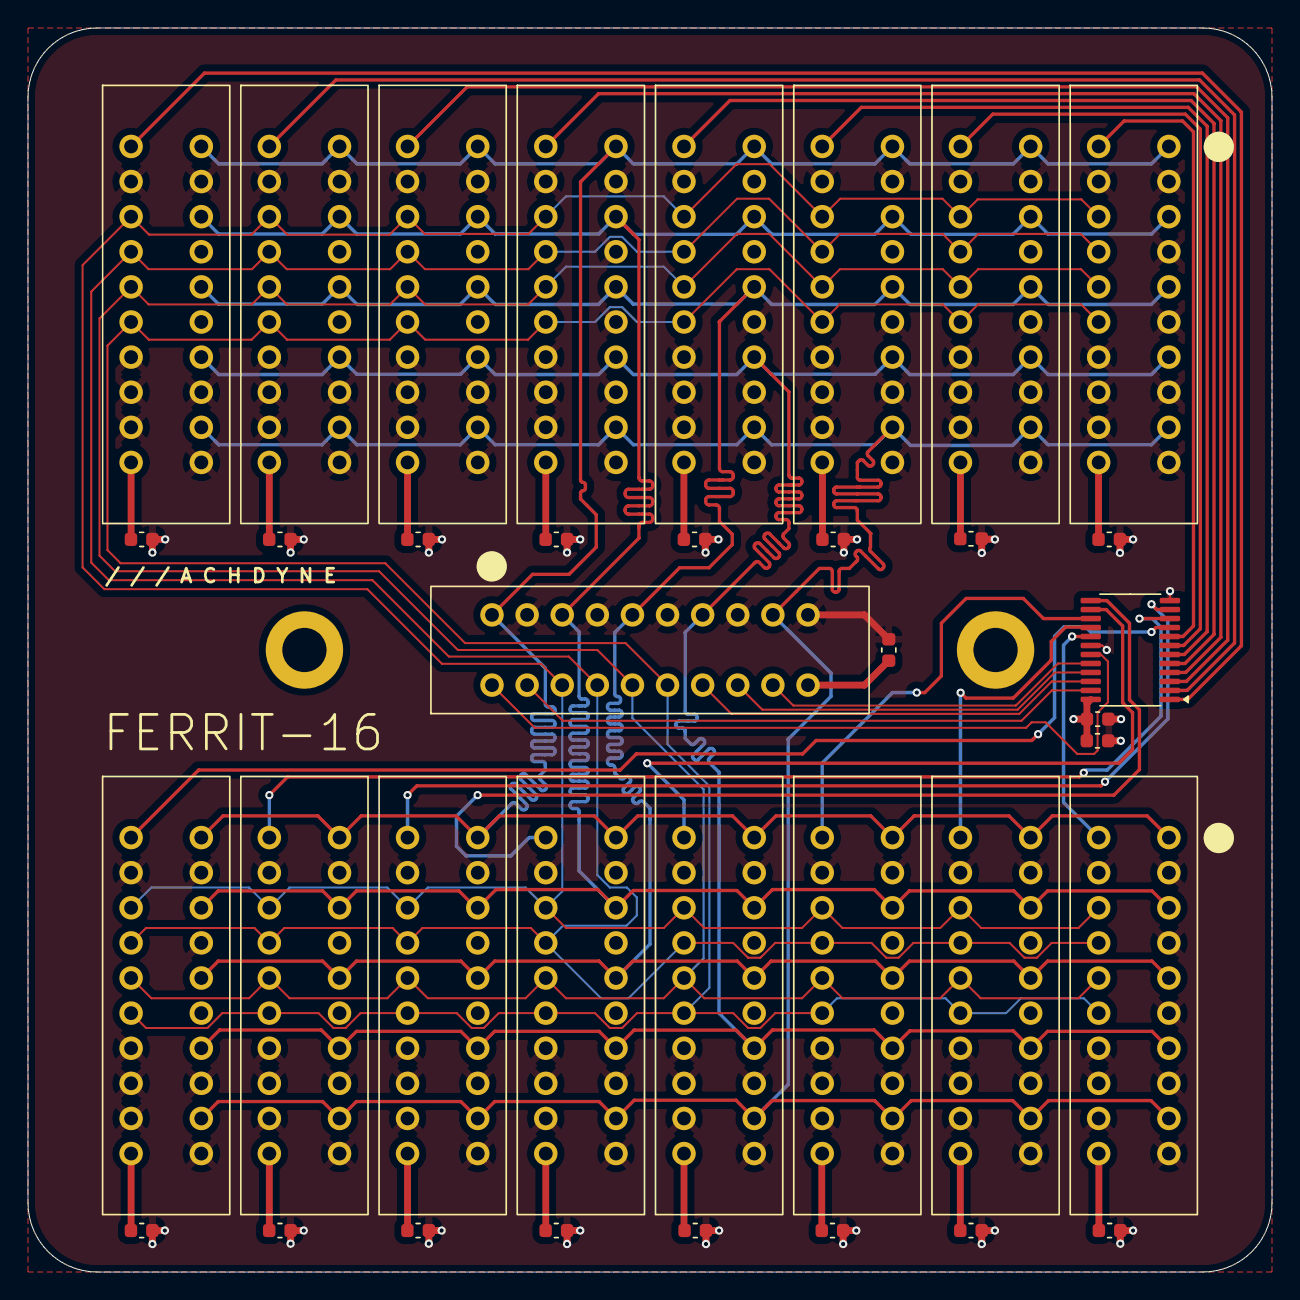
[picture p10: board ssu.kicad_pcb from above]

Board: 4 copper layers, 90.0 x 90.0 mm, 39 parts (0 on the bottom side), 32 nets.

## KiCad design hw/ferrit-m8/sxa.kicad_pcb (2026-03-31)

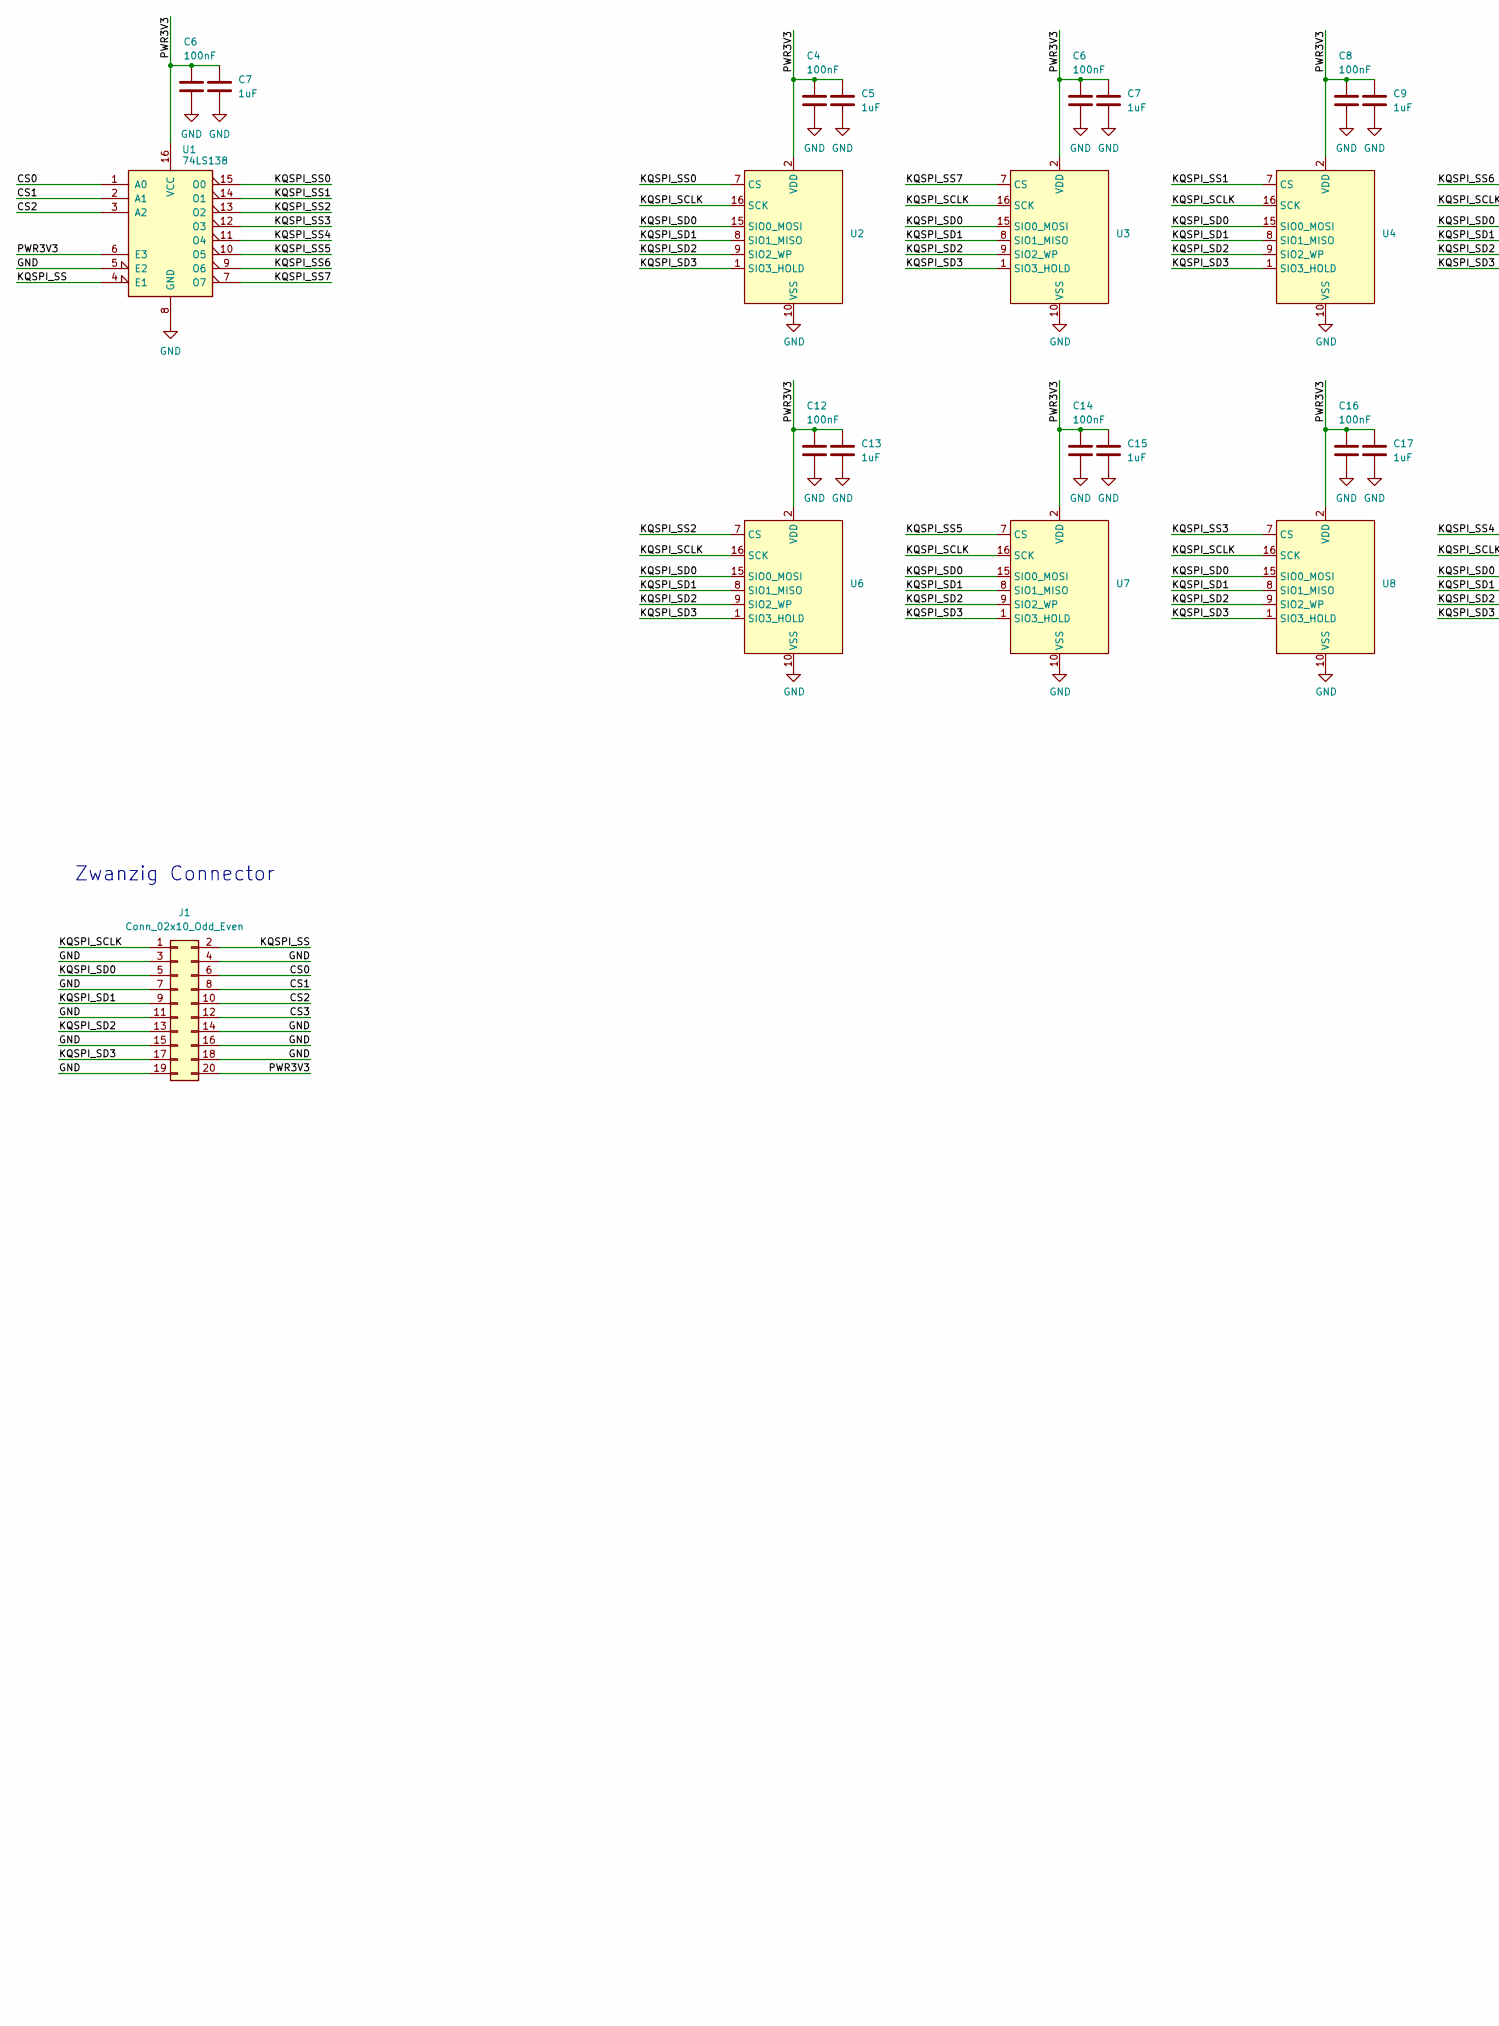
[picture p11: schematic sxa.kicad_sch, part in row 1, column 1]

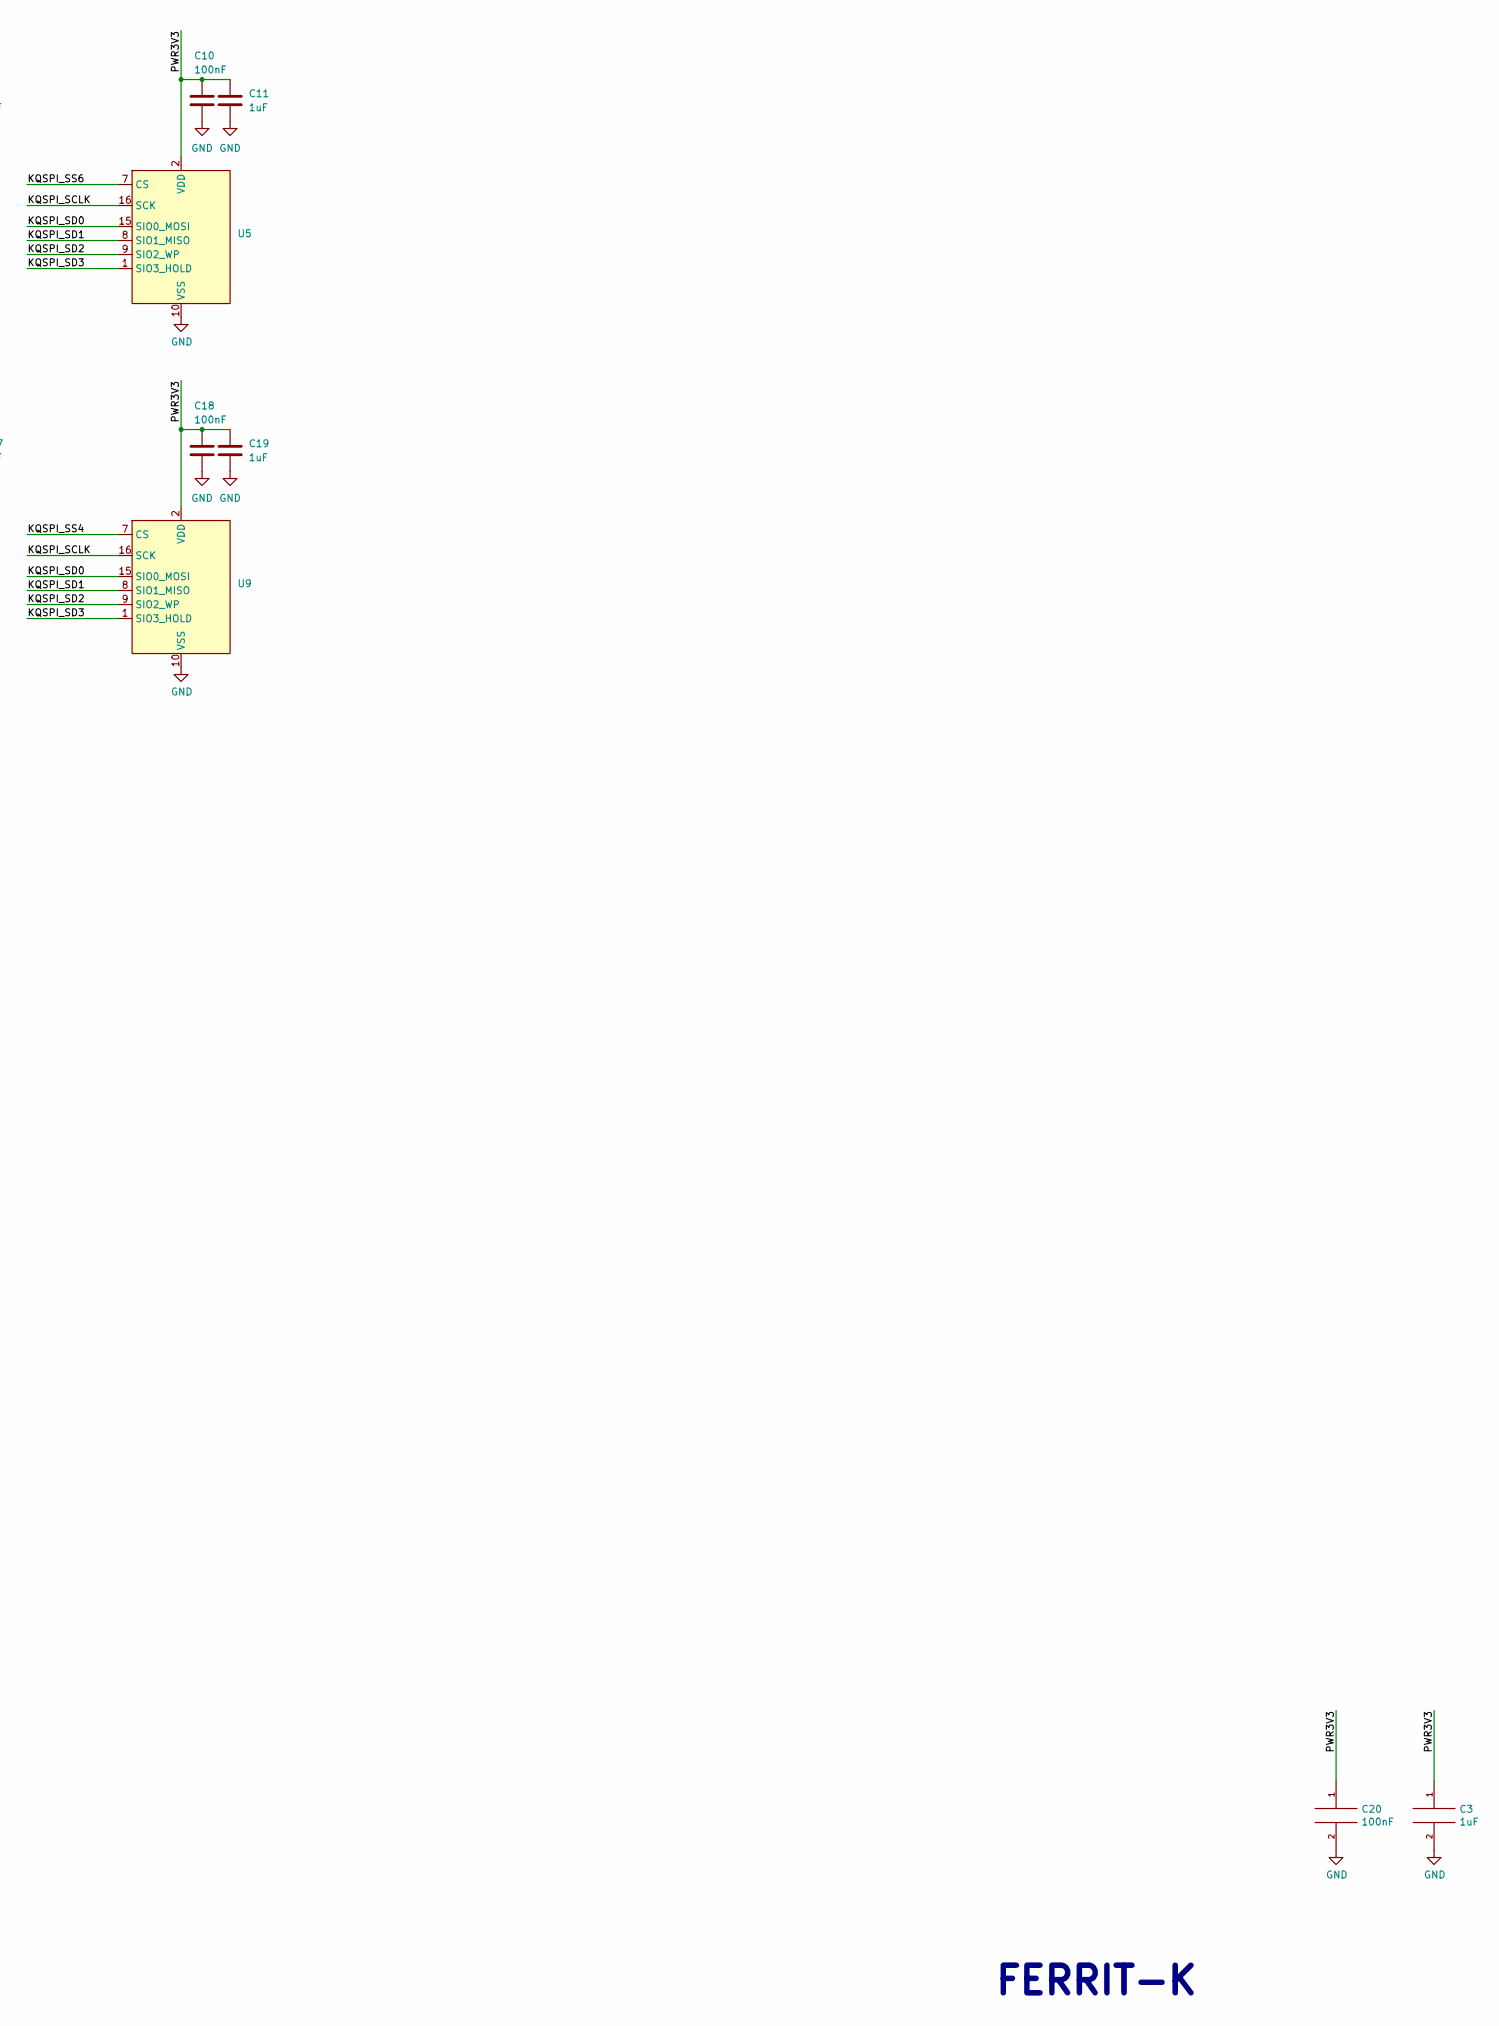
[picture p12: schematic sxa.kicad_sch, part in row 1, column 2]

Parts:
C3, C5, C7, C9, C11, C13, C15, C17, C19: 1uF; C_0603_1608Metric
C4, C6, C8, C10, C12, C14, C16, C18, C20: 100nF; C_0603_1608Metric
J1: Conn_02x10_Odd_Even; MACHDYNE_EDGE_20P
U1: 74LS138; TSSOP-16_4.4x5mm_P0.65mm
U2, U3, U4, U5, U6, U7, U8, U9: SOIC-16W_7.5x10.3mm_P1.27mm

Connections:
/CS0: J1.6, U1.1 (A0)
/CS1: J1.8, U1.2 (A1)
/CS2: J1.10, U1.3 (A2)
/CS3: J1.12
/KQSPI_SCLK: J1.1, U2.16 (SCK), U3.16 (SCK), U4.16 (SCK), U5.16 (SCK), U6.16 (SCK), U7.16 (SCK), U8.16 (SCK), U9.16 (SCK)
/KQSPI_SD0: J1.5, U2.15 (SIO0_MOSI), U3.15 (SIO0_MOSI), U4.15 (SIO0_MOSI), U5.15 (SIO0_MOSI), U6.15 (SIO0_MOSI), U7.15 (SIO0_MOSI), U8.15 (SIO0_MOSI), U9.15 (SIO0_MOSI)
/KQSPI_SD1: J1.9, U2.8 (SIO1_MISO), U3.8 (SIO1_MISO), U4.8 (SIO1_MISO), U5.8 (SIO1_MISO), U6.8 (SIO1_MISO), U7.8 (SIO1_MISO), U8.8 (SIO1_MISO), U9.8 (SIO1_MISO)
/KQSPI_SD2: J1.13, U2.9 (SIO2_WP), U3.9 (SIO2_WP), U4.9 (SIO2_WP), U5.9 (SIO2_WP), U6.9 (SIO2_WP), U7.9 (SIO2_WP), U8.9 (SIO2_WP), U9.9 (SIO2_WP)
/KQSPI_SD3: J1.17, U2.1 (SIO3_HOLD), U3.1 (SIO3_HOLD), U4.1 (SIO3_HOLD), U5.1 (SIO3_HOLD), U6.1 (SIO3_HOLD), U7.1 (SIO3_HOLD), U8.1 (SIO3_HOLD), U9.1 (SIO3_HOLD)
/KQSPI_SS: J1.2, U1.4 (E1)
/KQSPI_SS0: U1.15 (O0), U2.7 (CS)
/KQSPI_SS1: U1.14 (O1), U4.7 (CS)
/KQSPI_SS2: U1.13 (O2), U6.7 (CS)
/KQSPI_SS3: U1.12 (O3), U8.7 (CS)
/KQSPI_SS4: U1.11 (O4), U9.7 (CS)
/KQSPI_SS5: U1.10 (O5), U7.7 (CS)
/KQSPI_SS6: U1.9 (O6), U5.7 (CS)
/KQSPI_SS7: U1.7 (O7), U3.7 (CS)
/PWR3V3: C3.1, C4.1, C5.1, C6.1, C7.1, C8.1, C9.1, C10.1, C11.1, C12.1, C13.1, C14.1, C15.1, C16.1, C17.1, C18.1, C19.1, C20.1, J1.20, U1.6 (E3), U1.16 (VCC), U2.2 (VDD), U3.2 (VDD), U4.2 (VDD), U5.2 (VDD), U6.2 (VDD), U7.2 (VDD), U8.2 (VDD), U9.2 (VDD); also elsewhere on the board
GND: C3.2, C4.2, C5.2, C6.2, C7.2, C8.2, C9.2, C10.2, C11.2, C12.2, C13.2, C14.2, C15.2, C16.2, C17.2, C18.2, C19.2, C20.2, J1.3, J1.4, J1.7, J1.11, J1.14, J1.15, J1.16, J1.18, J1.19, U1.5 (E2), U1.8 (GND), U2.10 (VSS), U3.10 (VSS), U4.10 (VSS), U5.10 (VSS), U6.10 (VSS), U7.10 (VSS), U8.10 (VSS), U9.10 (VSS); also elsewhere on the board

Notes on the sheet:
FERRIT-K
Zwanzig Connector

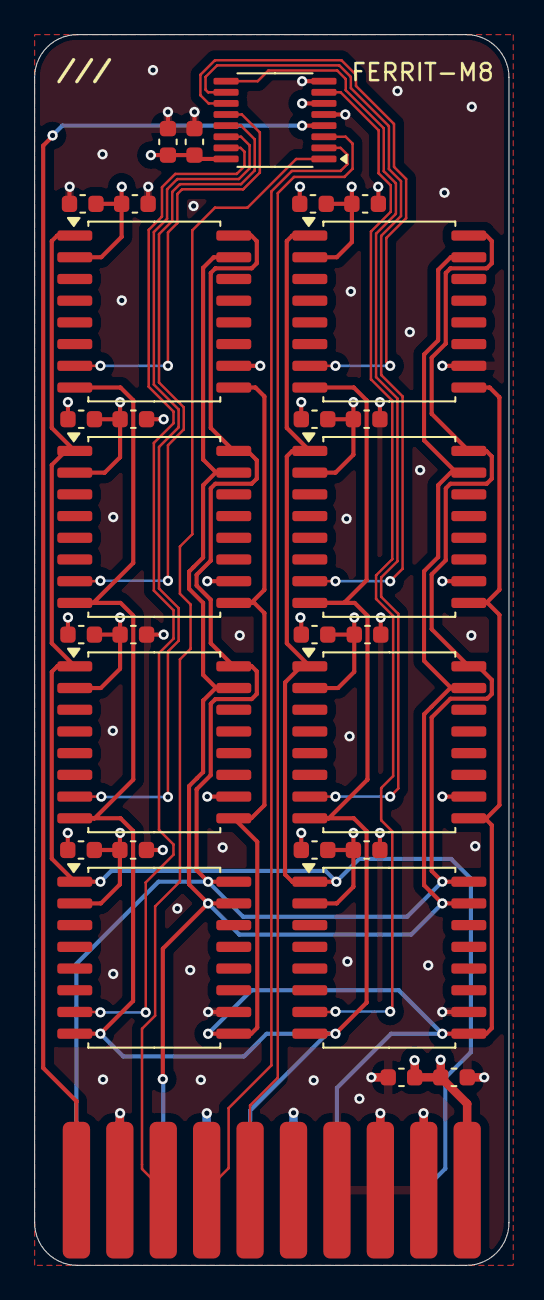
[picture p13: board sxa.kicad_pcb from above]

Board: 4 copper layers, 27.8 x 72.0 mm, 30 parts (0 on the bottom side), 19 nets.

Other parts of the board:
C1: 100nF; C_0603_1608Metric
C2: 1uF; C_0603_1608Metric

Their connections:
/PWR3V3: C1.1, C2.1; also elsewhere on the board
GND: C1.2, C2.2; also elsewhere on the board

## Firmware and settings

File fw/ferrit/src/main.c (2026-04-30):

/*
 * The MIT License (MIT)
 *
 * Copyright (c) 2019 Ha Thach (tinyusb.org)
 * Copyright (c) 2025 Lone Dynamics Corporation
 *
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
 */

#include <stdlib.h>
#include <stdio.h>
#include <string.h>

#include "pico/stdlib.h"
#include "tusb.h"

#include "ferrit.h"
#include "drv_fram.h"

//--------------------------------------------------------------------+
// MACRO CONSTANT TYPEDEF PROTYPES
//--------------------------------------------------------------------+

/* Blink pattern
 * - 250 ms  : device not mounted
 * - 1000 ms : device mounted
 * - 2500 ms : device is suspended
 */
enum {
  BLINK_NOT_MOUNTED = 250,
  BLINK_MOUNTED = 1000,
  BLINK_SUSPENDED = 2500,
};

static uint32_t blink_interval_ms = BLINK_NOT_MOUNTED;

void led_blinking_task(void);

/*------------- MAIN -------------*/
int main(void) {

	ferrit_init();
	fram_init();

	// init device stack on configured roothub port
	tud_init(BOARD_TUD_RHPORT);

	while (1) {
		tud_task(); // tinyusb device task
		led_blinking_task();
	}

}

//--------------------------------------------------------------------+
// Device callbacks
//--------------------------------------------------------------------+

// Invoked when device is mounted
void tud_mount_cb(void) {
  blink_interval_ms = BLINK_MOUNTED;
}

// Invoked when device is unmounted
void tud_umount_cb(void) {
  blink_interval_ms = BLINK_NOT_MOUNTED;
}

// Invoked when usb bus is suspended
// remote_wakeup_en : if host allow us  to perform remote wakeup
// Within 7ms, device must draw an average of current less than 2.5 mA from bus
void tud_suspend_cb(bool remote_wakeup_en) {
  (void) remote_wakeup_en;
  blink_interval_ms = BLINK_SUSPENDED;
}

// Invoked when usb bus is resumed
void tud_resume_cb(void) {
  blink_interval_ms = tud_mounted() ? BLINK_MOUNTED : BLINK_NOT_MOUNTED;
}

//--------------------------------------------------------------------+
// BLINKING TASK
//--------------------------------------------------------------------+
void led_blinking_task(void) {
	static uint64_t start_ms = 0;
	static bool led_state = false;

// Blink every interval ms
	if ((time_us_32() / 1000) - start_ms < blink_interval_ms) return; // not enough time
	start_ms += blink_interval_ms;

	gpio_put(F_LEDG, led_state);

	led_state = 1 - led_state; // toggle
}

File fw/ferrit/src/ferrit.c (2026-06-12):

/* 
 * FERRIT Firmware
 * Copyright (c) 2026 Lone Dynamics Corporation. All rights reserved.
 *
 */

#include <stdbool.h>
#include "pico/stdlib.h"
#include "hardware/pio.h"
#include "ferrit.h"
#include "ferrit_pio_spi.h"

pio_spi_t ferrit_spi;

void ferrit_init(void) {

	// rgb led
	gpio_init(F_LEDR); gpio_set_dir(F_LEDR, true); gpio_put(F_LEDR, 1);
	gpio_init(F_LEDG); gpio_set_dir(F_LEDG, true); gpio_put(F_LEDG, 1);
	gpio_init(F_LEDB); gpio_set_dir(F_LEDB, true); gpio_put(F_LEDB, 1);

	// WP and HOLD must be driven high before any CS is asserted
	// (no external pull-ups on board)
	gpio_init(F_SIO2); gpio_set_dir(F_SIO2, GPIO_OUT); gpio_put(F_SIO2, 1);
	gpio_init(F_SIO3); gpio_set_dir(F_SIO3, GPIO_OUT); gpio_put(F_SIO3, 1);

	// SS strobe (active low enable on SN74HC154)
	gpio_init(F_SS); gpio_set_dir(F_SS, GPIO_OUT); gpio_put(F_SS, 1);

#if !defined(FERRIT_1)
	// SS demux address bits (slot select 0-15)
	gpio_init(F_SS0); gpio_set_dir(F_SS0, GPIO_OUT); gpio_put(F_SS0, 0);
	gpio_init(F_SS1); gpio_set_dir(F_SS1, GPIO_OUT); gpio_put(F_SS1, 0);
	gpio_init(F_SS2); gpio_set_dir(F_SS2, GPIO_OUT); gpio_put(F_SS2, 0);
	gpio_init(F_SS3); gpio_set_dir(F_SS3, GPIO_OUT); gpio_put(F_SS3, 0);
#endif

	// CS demux address bits (chip select 0-15 on card)
	gpio_init(F_CS0); gpio_set_dir(F_CS0, GPIO_OUT); gpio_put(F_CS0, 0);
	gpio_init(F_CS1); gpio_set_dir(F_CS1, GPIO_OUT); gpio_put(F_CS1, 0);
	gpio_init(F_CS2); gpio_set_dir(F_CS2, GPIO_OUT); gpio_put(F_CS2, 0);
	gpio_init(F_CS3); gpio_set_dir(F_CS3, GPIO_OUT); gpio_put(F_CS3, 0);

	// PIO SPI — bypasses the SPI0/SPI1 GPIO mismatch on FERRIT-CY
	// clk_div=2 -> SCK ~7.8 MHz at 125MHz sys_clk
	pio_spi_init(&ferrit_spi, pio0, 0, F_SCK, F_MOSI, F_MISO, 2.0f);

}

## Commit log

2026-03-31 add prototype hardware designs
    [ssu.kicad_pcb, ssu.kicad_sch, sxa.kicad_pcb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]
2026-04-04 cleanup schematics
    [ssu.kicad_sch, sxa.kicad_sch, sxy.kicad_sch]
2026-04-06 update designs
    [ssu.kicad_pcb, ssu.kicad_sch, sxy.kicad_pcb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]
2026-06-12 add ferrit-1 (edelstahl)
    [ssx.kicad_pcb, ssx.kicad_sch]
2026-06-28 add edelstahl case
2026-10-09 usb-msc: fix unmount by tracking per-LUN eject state
    The host ejects a LUN by sending START STOP UNIT with LoEj=1,
    Start=0. Previously tud_msc_start_stop_cb ignored load_eject
    entirely, so tud_msc_test_unit_ready_cb kept reporting the medium
    as present — causing Linux and macOS to immediately rescan and
    remount the disk, making eject appear to have no effect.
    Fix mirrors the approach in machdyne/ebenstahl:
    - Add f_ejected[F_MAX_LUN] to track eject state per LUN
    - tud_msc_start_stop_cb sets/clears the flag when LoEj is set
    - tud_msc_test_unit_ready_cb returns MEDIUM NOT PRESENT for ejected LUNs
    - Read/write callbacks also return an error on ejected medium
    - usb_msc_reset_eject() clears all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

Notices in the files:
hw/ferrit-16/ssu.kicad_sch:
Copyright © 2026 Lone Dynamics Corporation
